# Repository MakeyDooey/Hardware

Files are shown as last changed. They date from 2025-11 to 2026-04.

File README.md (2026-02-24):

# Hardware
This includes all CAD files, PCB designs, schematics, datasheets, and designs. (includes enclosure and modularity components)

In it's current state I do not have a .gitignore for this repo. I will make one eventually and organize the repo more, but for now all KiCAD files are saved in the Schematic Folder as they are saved on my local computer

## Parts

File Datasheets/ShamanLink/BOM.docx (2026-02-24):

# ShamanLink

- ~~MicroSD Connector:~~ ~~https://www.digikey.com/en/products/detail/molex/0475710001/3262277~~ ~~$1.03~~
- ~~DualTVSProtection~~~~:~~~~https://www.digikey.com/en/products/detail/stmicroelectronics/USBLC6-2SC6/1040559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 ~~$0.36 x3~~
- ~~Tactile Button:~~ ~~https://www.digikey.com/en/products/detail/c-k/PTS645SL43SMTR92-LFS/3861373~~ ~~$0.36~~
- ~~LDO:~~ ~~https://www.digikey.com/en/products/detail/diodes-incorporated/AP7361C-33Y5-13/5638323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 ~~$0.50~~
- ~~Priority MUX:~~ ~~https://www.ti.com/product/TPS2117~~ ~~$1.15~~
- ~~Crystal:~~ ~~https://www.digikey.com/en/products/detail/ecs-inc/ECS-160-20-46X/2676589~~ ~~$0.37~~
- ~~MCU:~~ ~~https://www.digikey.com/en/products/detail/nxp-usa-inc/LPC55S69JBD64K/10649974~~ ~~$8.45~~
- ~~USB-C Receptacle:~~ ~~https://www.digikey.com/en/products/detail/gct/USB4105-GF-A/11198441~~ ~~$0.78~~
- ~~DualTVSProtection:~~~~https://www.digikey.com/en/products/detail/stmicroelectronics/USBLC6-2SC6/1040559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 ~~$0.36 x1~~
- ~~Polyfuse:~~ ~~1206L075/13.2WR~~ ~~https://www.digikey.com/en/products/detail/littelfuse-inc/1206L075-13-2WR/2520739~~ ~~$0.57~~
- ~~TVSProtection:~~ ~~https://www.arrow.com/en/products/sm712-02htg/littelfuse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 ~~$0.59~~
- ~~Connector:~~ ~~https://www.digikey.com/en/products/detail/jst-sales-america-inc/S6B-XH-A/1651034~~ ~~$0.27~~
- ~~Transceiver:~~ ~~https://www.ti.com/product/THVD1450/part-details/THVD1450D~~ ~~$2.78 SOIC option~~
- ~~SWDTagConnect:~~ ~~https://www.tag-connect.com/product/tc2030-idc-nl~~ ~~$33.95~~
- ~~MulticolorLED:~~ ~~https://www.digikey.com/en/products/detail/w%C3%BCrth-elektronik/150141M173100/4489960~~ ~~$0.50~~
- ~~Header Pins:~~ ~~https://www.digikey.com/en/products/detail/sullins-connector-solutions/PRPC036SAAN-RC/2775218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 ~~$0.85 for 3xmore than needed~~
- ~~SMD Ferrite Beads:~~ ~~MFBW1V1~~~~608-601-R~~ ~~https://www.digikey.com/en/products/detail/eaton-electronics-division/MFBW1V1608-221-R/13161138~~ ~~6x$0.10;~~
- ~~0805 ( >=0.125W rating; 1% tolerance; thick film) SMD Resistors~~~~:~~ ~~5x10k; 1x22;~~ ~~1x10k; 1x110k; 1x56k; 1x100k;~~ ~~2x5.1k; 1x10k; 1x20k; 1x1M~~ ~~2x10k;~~ ~~4x33;3x10k~~ ~~6x1k; 1x330; 2x10k; 2x0; 2x100k~~ ~~https://www.amazon.com/Chanzon-Resistor-Tolerance-Resistors-Certificated/dp/B08RYMY6XK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
- ~~1206 (>=0.25W rating) SMD Resistor:~~ ~~1x120~~ ~~https://www.amazon.com/dp/B08RYMYWG9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 (https://www.amazon.com/dp/B08RYMYWG9?s=industrial&sp_csd=d2lkZ2V0TmFtZT1zcF9kZXRhaWw)
- ~~0805 SMD Capacitors (>10V rating on all; dielectric matters):~~ ~~1x0.1uF; 1x10uF;~~ ~~2x10uF; 2x100nF; 2x4.7uF; 3x0.1uF;~~ ~~2x33pF;~~ ~~1x10nF; 1x 4.7nF; 10x0.1uF; 1x1uF; 2x10uF; 2x47pF; 1x100nF;~~ ~~2x0.1uF; 1x10uF;~~ ~~2x0.1uF~~~~;1x10uF~~ ~~1x0.1uF~~~~https://www.amazon.com/0805-Capacitor-Capacitors-Assortment-Folder/dp/B0D6RW7CZ8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
- ~~1206~~ ~~SMD Capacitors (>25V rating on all; dielectric matters)~~ ~~1x22uF;~~ ~~2x22uF;~~ ~~https://www.mouser.com/ProductDetail/Murata-Electronics/GRT31CC71E226ME13K?qs=xZFQr2mActe1lTnk7kyUaA%3D%3D~~
- ~~SMD Inductors:~~ ~~CDRH2D11NP-4R7NC~~ ~~https://www.digikey.com/en/products/detail/sumida-america-inc/CDRH2D11NP-4R7NC/2620830~~ ~~1x$0.75~~
- ~~0805 SMD LEDs:~~ ~~see the .csv file for links and datasheets 6->green,green,blue,yellow,yellow,red 6x$0.19 //make sure Vf < 3V on all LEDs and Vf > 1.5V for 2 LEDs in series with 33 ohm resistors~~
- ~~Programmer~~~~:~~ ~~https://www.digikey.com/en/products/detail/nxp-usa-inc/MCU-LINK/13536147~~
- ~~Solder materials~~~~: solder wire:~~ ~~https://www.amazon.com/Rosin-Solder-Electrical-Soldering-0-3mm/dp/B08M5XDKFG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 ~~, solder paste:~~ ~~https://www.amazon.com/Solder-Paste-clean-63Sn-syringe/dp/B07B3VHPJ8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 ~~, desoldering braid~~ ~~https://www.amazon.com/TOWOT-Desoldering-Disassemble-Electrical-Components/dp/B0943PDCC4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

# GeminiCHECKPowerBudgetShamanLink

### 1. The Power Supply Capability

- Source (USB-C): Standard USB 2.0 ports provide 500mA. USB 3.0 ports provide 900mA.
- Safety Fuse (Polyfuse 1206L075): This has a "Hold Current" of 750mA. This is your absolute input limit before the fuse starts acting like a resistor and cutting power.
- Voltage Regulator (LDO AP7361C):
  - Max Current: 1.0A (1000mA).
  - Constraint: While it can push 1A, it is limited by heat (see thermal check below).

Available Power Budget: Conservatively 500mA (limited by standard USB ports).

### 2. The Power Consumption (The Load)

We will calculate the "Worst Case" scenario (everything turned on and transmitting at once) for the 3.3V Rail.

Component | State | Estimated Current (mA) | Notes
LPC55S69 MCU | Active Run (96MHz) | ~18 mA | Using internal DC-DC (implied by 4.7µH inductor).
MicroSD Card | Write Mode (Peak) | ~100 mA | This is the biggest variable. Some cards spike higher, but 100mA is a safe standard budget.
THVD1450 (RS485) | Transmitting | ~60 mA | Assumes driving a standard 54Ω termination load.
6x LEDs | All On | ~8 mA | Your BOM lists 1kΩ resistors. $(3.3V - 2V) / 1000\Omega = 1.3mA$ per LED.
Multicolor LED | White (RGB On) | ~15 mA | Assumes ~5mA per channel.
TPS2117 Mux | On | ~0.1 mA | Negligible quiescent current.
Passive Leaks | TVS / Caps | ~0.1 mA | Negligible.
TOTAL (Peak) | | ~201.2 mA

Total Estimated Max Load: ~200 mA

### 3. Verification & Safety Margins

#### A. Current Capability [PASS]

- Demand: ~200mA
- Supply: 500mA (USB) / 1000mA (LDO) / 750mA (Fuse)
- Result: You are using roughly 40% of your available USB power. You have plenty of headroom for the MCU to boost its clock speed or for high-performance SD cards.

#### B. LDO Thermal Analysis [PASS]

This is critical. You are dropping 5V down to 3.3V. That extra voltage turns into heat.

- Voltage Drop: $5V - 3.3V = 1.7V$
- Current Load: $0.2A$ (200mA)
- Power Dissipated: $P = V \times I = 1.7 \times 0.2 = \mathbf{0.34 Watts}$

Your LDO (AP7361C) usually comes in SOT-89 or SOT-223 packages.

- Estimated Temp Rise: A standard SOT-89 package rises ~50°C per Watt.
- Calculation: $0.34W \times 50^\circ C/W \approx 17^\circ C$ rise.
- Result: If your room is 25°C, the LDO will run at roughly 42°C. This is warm to the touch but completely safe (well below the 125°C limit).

### 4. Special Component Notes

1. Inductor (CDRH2D11NP-4R7NC): This 4.7µH inductor matches the requirements for the LPC55S69 Internal DC-DC Converter. This is good design; it keeps the MCU current consumption low.
2. Resistors: The 1kΩ resistors you selected for the LEDs will make them quite dim (perfect for indicators that don't blind the user). If you want them brighter, you have plenty of power budget to swap them for 330Ω resistors later.
3. Polyfuse: The 750mA hold current is perfect. It protects the USB port without tripping during normal SD card spikes.

### Conclusion

Your power budget is solid. You have approximately 300mA of spare capacity on the 3.3V rail.

Component | State | Estimated Current (mA)
LPC55S69 MCU | Active Run (96MHz) | ~18 mA
MicroSD Card | Write Mode (Peak) | ~100 mA
THVD1450 (RS485) | Transmitting | ~60 mA
6x LEDs | All On | ~8 mA
Multicolor LED | White (RGB On) | ~15 mA
TPS2117 Mux | On | ~0.1 mA
Passive Leaks | TVS / Caps | ~0.1 mA
TOTAL (Peak) | Does not include powering a target board | ~201.2 mA

Power Supply: ~500mA max from USB 2.0

Power Usage: ~40%

This is the "sanity check" phase, and it is arguably the most critical step before you order. You are looking to verify three things: Current Capability (will traces melt?), Voltage Drop (will the voltage be too low by the time it reaches the chip?), and Thermals (will the LDO burn up?).

Here is your step-by-step guide to verifying your power design using KiCad’s built-in tools and some simple math.

### Step 1: Create Your "Power Budget"

Before you measure anything, you need to know what you are measuring against. You cannot verify a trace if you don't know how many Amps are flowing through it.

- List your max currents:
  - USB Input (5V): What is the max current your board will draw? (likely < 500mA for a standard USB 2.0 device).
  - LDO Output (3.3V): How much does the MCU + LEDs + Peripherals consume? (LPC55S69 is usually < 20mA, but LEDs can add up).
  - Target Power: If you are powering an external target, how much current does it need?

Example Budget:

- Input 5V: 500mA (Max)
- Main 3.3V Rail: 200mA (MCU + LED + headroom)

### Step 2: Verify Trace Widths (KiCad Calculator)

You selected trace widths earlier (0.2mm, 0.4mm, 0.8mm). Now, let's scientifically prove they are big enough.

1. Open KiCad Calculator: In the main KiCad project window, click the icon that looks like a calculator (or Tools -> Calculator Tools).
2. Go to the "Track Width" Tab.
3. Enter your parameters:
  - Current: Enter your max current (e.g., 0.5A for the USB line).
  - Temperature Rise: Standard is 10°C. (This means you are okay with the trace getting 10 degrees hotter than the room).
  - Trace Thickness: Standard 1oz copper is 35µm (0.035mm).
  - Trace Length: Enter a rough estimate (e.g., 20mm).
4. Result: Look at the "External Layer Track Width".
  - Example: For 0.5A, KiCad might say you need only 0.15mm.
  - Your Design: You used 0.8mm for power. Verdict: PASS (with huge safety margin).

Rule of Thumb: A 0.3mm trace can easily handle 1 Amp on external layers. Your 0.8mm power traces are likely bulletproof.

### Step 3: Check Your Vias (The Bottleneck)

Vias are the chokepoints of power. A single standard via cannot handle as much current as a wide trace.

1. In the Calculator: Switch to the "Via" tab (or look at the via section in Track Width).
2. Enter your Via size:
  - Hole Diameter: 0.3mm (standard small via) or 0.4mm (power via).
  - Plating Thickness: Standard is 18µm - 25µm.
3. Check the Current:
  - A single 0.3mm via can usually handle about 0.3A - 0.5A comfortably.
4. The Fix: If you need to pass 1A, use multiple vias.
  - Rule: Always use at least two vias for any power connection (input, output, ground). This adds redundancy and lowers resistance.
  - Action: Go to your layout and verify that your USB Connector Ground pins and LDO Ground tab have multiple vias stitching them to the Ground Plane.

### Step 4: The "LDO Thermal" Check (Critical!)

This is the most common failure point. Your LDO drops 5V to 3.3V. That energy is turned into heat.

1. Calculate Power Dissipation: $$P = (V_{in} - V_{out}) \times I_{load}$$
  - $V_{in} = 5V$
  - $V_{out} = 3.3V$
  - $I_{load} = 0.2A$ (Example)
  - $P = (5 - 3.3) \times 0.2 = 1.7 \times 0.2 = \mathbf{0.34 Watts}$
2. Check the Datasheet: Look for the "Thermal Resistance" ($R_{\theta JA}$) of your LDO package (e.g., SOT-23 or SOT-223).
  - SOT-23: A tiny package might heat up by $200^\circ C$ per Watt.
  - Calculation: $0.34W \times 200^\circ C/W = \mathbf{68^\circ C \text{ rise}}$.
  - Result: If your room is $25^\circ C$, the chip will be $93^\circ C$. That is HOT but safe (most silicon survives to $125^\circ C$).
3. The Fix: If the calculation shows over $100^\circ C$:
  - Use a bigger package (SOT-223 instead of SOT-23).
  - Add more copper area around the tab (the heatsink).
  - Add "Thermal Vias" in the central pad to dump heat into the ground plane.

### Step 5: Verify Passive Components

1. Resistors: Check any resistor carrying significant current (like LED current limiters).
  - $P = I^2 R$.
  - Example: 20mA through a 100-ohm resistor. $0.02^2 \times 100 = 0.04W$.
  - Rating: A standard 0402 resistor is rated for 0.063W (1/16W). This is close! An 0603 (0.1W) would be safer.
2. Inductors/Ferrite Beads: Check the "Rated Current" in the datasheet.
  - If your USB input has a Ferrite Bead, ensure it is rated for at least 1.5x your expected current (e.g., rated for 1A if you expect 500mA).

### Summary Checklist

1. [ ] Traces: Are power traces wider than the Calculator recommendation? (0.8mm is likely great).
2. [ ] Vias: Do main power connections have at least 2 vias?
3. [ ] LDO Heat: Did you calculate the temperature rise? Is it under $100^\circ C$?
4. [ ] Passives: Are your resistors big enough (0603 vs 0402) for the power they dissipate?

Do you want to run the calculation for your specific LDO right now? If you give me the Part Number and your Estimated Current, I can tell you if it will overheat.

# MainTotemDemo

# MotorTotemDemo

# ModuleTotemDemo

# Scratchpad

## 1. Electrical & Physical Cleanup

- Run the Design Rules Checker (DRC): This is the most important step. Click the Bug icon in the top toolbar. It will catch any accidental shorts, traces that are too close together, or vias that didn't actually connect to the ground plane.
- Refill All Zones: Press the B key. This recalculates all copper pours. If you moved a via or trace, the copper plane might have a "hole" in it that needs to be filled.
- Check for "Islands": Look for any floating bits of copper that aren't connected to anything. KiCad’s DRC will usually flag these as "Unconnected items."
- Inspect Thermal Vias: Verify that your ground vias for U3 still show the GND net and are correctly merged into the bottom ground plane.

## 2. Silkscreen & Aesthetics

- Fix Overlapping Text: As we discussed, make sure C17, U3, and other labels aren't sitting on top of via holes or pads.
- Check Component Polarity: Ensure that "Pin 1" markers (dots or notches) are visible on the silkscreen so you don't solder the chips on backward.
- Add Board Information: It is always a good idea to add your name, the project title, the date, and a version number (e.g., "v1.0") to the F.Silk or B.Silk layer.
- Add Logos: If you want a "Certified Open Source" logo or a personal icon, add it now!

## 3. Hand-Soldering Optimizations

- Check Mask Openings: Use the 3D Viewer (Alt + 3) to confirm that the purple/pink areas (solder mask openings) are present on all pads you need to solder.
- Verify Clearance: Ensure there is enough physical room between components for your soldering iron tip to reach the pads without melting the plastic casing of a neighboring part.

## 4. Output Generation (The "Manufacturing" Files)

Once the DRC shows 0 Errors and 0 Warnings, it’s time to generate the files for the factory:

1. Generate Gerbers: Go to File > Fabrication Outputs > Gerbers (.gbr). Select all copper layers, Silkscreen, Mask, and the Edge.Cuts (board outline) layer.
2. Generate Drill Files: In the same menu, click Generate Drill Files. Use the default settings (Excellon format).
3. Create a ZIP: Put all the generated .gbr and .drl files into a single ZIP folder. This is what you will upload to the manufacturer's website.

## 5. Final Visual Audit

- The "Paper Test": Some designers print the layout at 1:1 scale on a piece of paper and physically place their components on the paper to ensure the footprints are the correct size.
- Inspect the Bottom Layer: Flip the 3D model over. Ensure your ground plane is solid and your thermal vias are clearly visible for that "solder injection" trick.

6. Check that traces width all match their power amounts

7. Check your paper to make sure you have done everything

8. Read through all datasheets to make sure you followed all instructions and that the components you used all correctly match your power requirements.

9. Document out all of the PCB design process with specific steps so it’s easy to follow again and include everything you learned such as the powerpoint presentation tips on width for traces etc etc. all the Gemini stuff. Go through every prompt

10. Upload everything to GitHub and organize all of the ShamanLink documentation into the GitHub as well….. Email erosen

11. Final verifications of everything and order the PCB

12. Make sure all vias that need to be tented are tented

Root Power RS485Transceiver HeaderLEDs MainTotemHeader MicroSD Clocks

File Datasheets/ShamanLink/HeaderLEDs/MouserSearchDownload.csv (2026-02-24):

Mouser Part Number | Mfr Part Number | Mfr. | Datasheet | Availability | Pricing | RoHS | Lifecycle | Product Detail | Product | Mounting Style | Package / Case | Wavelength/Color Temperature | Illumination Color | If - Forward Current | Vf - Forward Voltage | Power Rating | Lens Color | Lens Dimensions | Lens Shape | Lens Transparency | Series | Packaging
710-150080GS75000 | 150080GS75000 | Wurth Elektronik | https://www.we-online.com/components/products/datasheet/150080GS75000.pdf | 84,051 In Stock | ="$0.19" | RoHS Compliant |  | https://www.mouser.com/ProductDetail/Wurth-Elektronik/150080GS75000 | Green LEDs | SMD/SMT | 0805 (2012 metric) | 520 nm | Green | 20 mA | 3.2 V | 105 mW | Colorless | 1.4 mm x 1.25 mm | Rectangular | Water Clear | WL-SMCW | Reel, Cut Tape, MouseReel
710-150080VS75000 | 150080VS75000 | Wurth Elektronik | https://www.we-online.com/components/products/datasheet/150080VS75000.pdf | 23,543 In Stock | ="$0.19" | RoHS Compliant |  | https://www.mouser.com/ProductDetail/Wurth-Elektronik/150080VS75000 | Green LEDs | SMD/SMT | 0805 (2012 metric) | 570 nm | Green | 20 mA | 2 V | 72 mW | Colorless | 1.4 mm x 1.25 mm | Rectangular | Water Clear | WL-SMCW | Reel, Cut Tape, MouseReel
710-150080YS75000 | 150080YS75000 | Wurth Elektronik | https://www.we-online.com/components/products/datasheet/150080YS75000.pdf | 29,472 In Stock | ="$0.19" | RoHS Compliant |  | https://www.mouser.com/ProductDetail/Wurth-Elektronik/150080YS75000 | Yellow LEDs | SMD/SMT | 0805 (2012 metric) | 590 nm | Yellow | 20 mA | 2 V | 72 mW | Colorless | 1.4 mm x 1.25 mm | Rectangular | Water Clear | WL-SMCW | Reel, Cut Tape, MouseReel
710-150080BS75000 | 150080BS75000 | Wurth Elektronik | https://www.we-online.com/components/products/datasheet/150080BS75000.pdf | 21,273 In Stock | ="$0.19" | RoHS Compliant |  | https://www.mouser.com/ProductDetail/Wurth-Elektronik/150080BS75000 | Blue LEDs | SMD/SMT | 0805 (2012 metric) | 470 nm | Blue | 20 mA | 3.2 V | 105 mW | Colorless | 1.4 mm x 1.25 mm | Rectangular | Water Clear | WL-SMCW | Reel, Cut Tape, MouseReel
710-150080RS75000 | 150080RS75000 | Wurth Elektronik | https://www.we-online.com/components/products/datasheet/150080RS75000.pdf | 71,734 In Stock | ="$0.19" | RoHS Compliant |  | https://www.mouser.com/ProductDetail/Wurth-Elektronik/150080RS75000 | Red LEDs | SMD/SMT | 0805 (2012 metric) | 625 nm | Red | 20 mA | 2 V | 72 mW | Colorless | 1.4 mm x 1.25 mm | Rectangular | Water Clear | WL-SMCW | Reel, Cut Tape, MouseReel
710-150080AS75000 | 150080AS75000 | Wurth Elektronik | https://www.we-online.com/components/products/datasheet/150080AS75000.pdf |  | ="$0.25" | RoHS Compliant |  | https://www.mouser.com/ProductDetail/Wurth-Elektronik/150080AS75000 | Amber LEDs | SMD/SMT | 0805 (2012 metric) | 605 nm | Amber | 20 mA | 2 V | 72 mW | Colorless | 1.4 mm x 1.25 mm | Rectangular | Water Clear | WL-SMCW | Reel, Cut Tape, MouseReel
710-150080SS75000 | 150080SS75000 | Wurth Elektronik | https://www.we-online.com/components/products/datasheet/150080SS75000.pdf |  | ="$0.19" | RoHS Compliant |  | https://www.mouser.com/ProductDetail/Wurth-Elektronik/150080SS75000 | Red LEDs | SMD/SMT | 0805 (2012 metric) | 630 nm | Red | 20 mA | 1.9 V | 72 mW | Colorless | 1.4 mm x 1.25 mm | Rectangular | Water Clear | WL-SMCW | Reel, Cut Tape, MouseReel

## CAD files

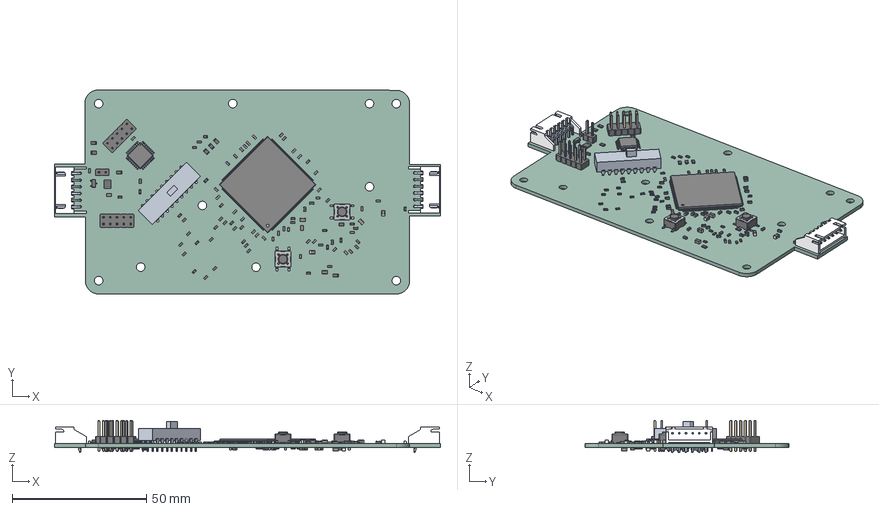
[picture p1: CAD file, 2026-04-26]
CAD/MainTotem_Rev1.step
143.9 x 76.1 x 11.9 mm
R_0603_1608Metric x 57
C_0603_1608Metric x 59
R_0805_2012Metric x 8
SOT-23
SW_SPST_PTS645Sx43SMTR92 x 2
C_0805_2012Metric x 9
LQFP-176
PinHeader_1x02_P2.54mm_Vertical
SxB-XH-A_6 x 2
pin^SxB-XH-A ass_bent x 4
pin^SxB-XH-A ass x 8
6PDTSwitch
R_1210_3225Metric
PinHeader_2x05_P2.54mm_Vertical x 2
STM32G0
MainTotem_Rev1_PCB

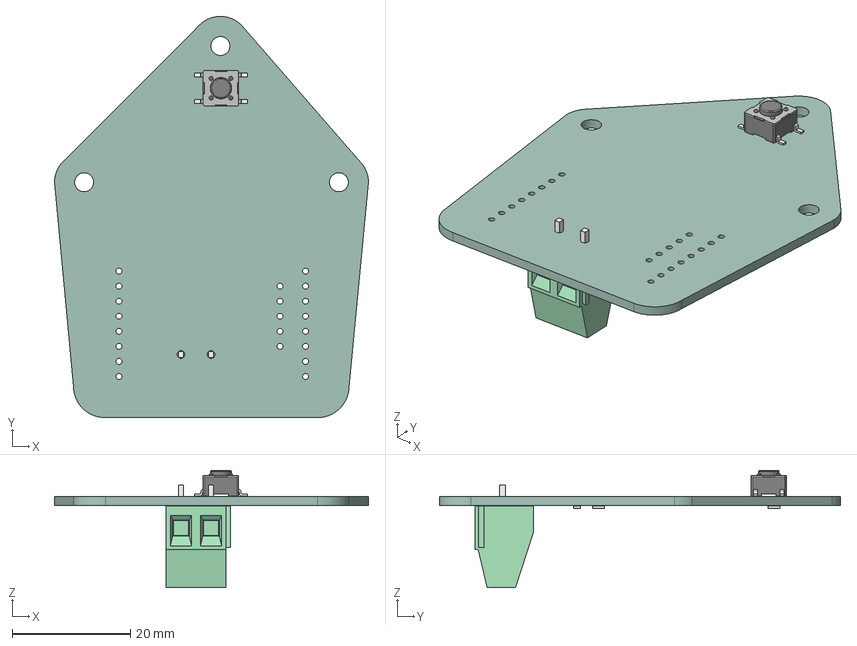
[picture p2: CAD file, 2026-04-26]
CAD/ComputerVisionModule_Rev1.step
53.0 x 67.7 x 19.8 mm
SW_SPST_PTS645Sx43SMTR92
TerminalBlock_Phoenix_MKDS-1,5-2-5.08_1x02_P5.08mm_Horizontal
R_0805_2012Metric x 3
ComputerVisionModule_Rev1_PCB

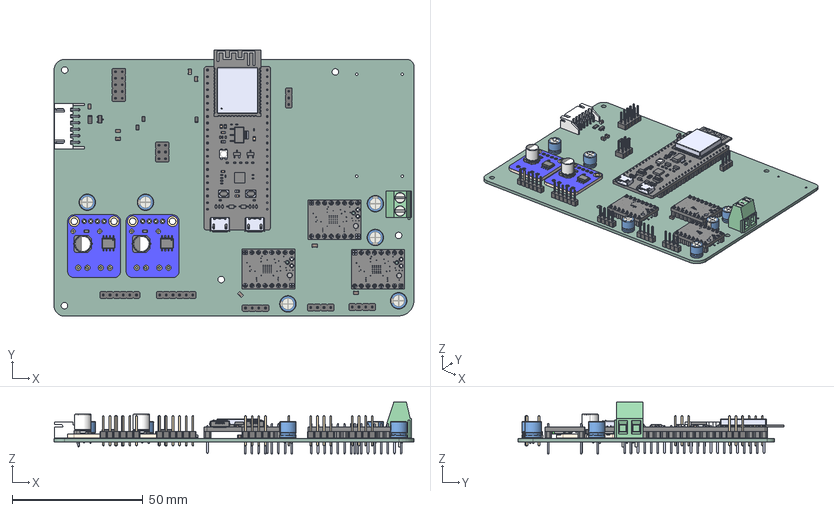
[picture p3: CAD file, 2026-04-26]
CAD/MotorTotem_Rev1.step
137.8 x 102.0 x 19.9 mm
TMC2209_SILENTSTEPSTICK x 3
R_0805_2012Metric x 3
CP_Radial_D6.3mm_P2.50mm x 6
PinHeader_2x05_P2.54mm_Vertical
C_0805_2012Metric x 8
Panasonic_D_22uF_63V_Panasonic_D_22uF_63V x 2
DRV8871_DRV8871 x 2
ESP32-S3-DEVKITC-1-N8R8
TerminalBlock_Phoenix_MKDS-1,5-2-5.08_1x02_P5.08mm_Horizontal
PinHeader_1x04_P2.54mm_Vertical x 3
PinHeader_2x03_P2.54mm_Vertical
SOT-23
PinHeader_1x06_P2.54mm_Vertical x 2
R_1206_3216Metric
PinHeader_1x03_P2.54mm_Vertical
SxB-XH-A_6
pin^SxB-XH-A ass_bent x 2
pin^SxB-XH-A ass x 4
MotorTotem_Rev1_PCB

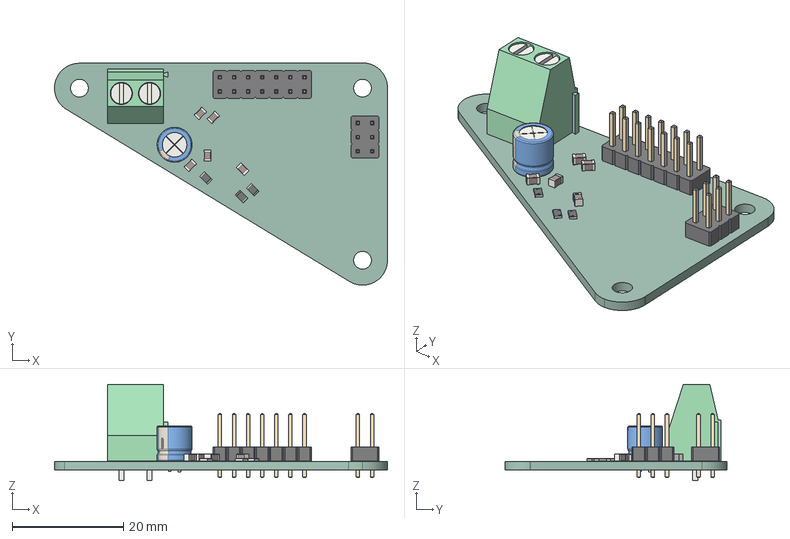
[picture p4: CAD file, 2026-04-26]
CAD/TouchScreenModule_Rev1.step
60.0 x 40.1 x 17.3 mm
R_0805_2012Metric x 3
PinHeader_2x07_P2.54mm_Vertical
C_0805_2012Metric x 5
PinHeader_2x03_P2.54mm_Vertical
TerminalBlock_Phoenix_MKDS-1,5-2-5.08_1x02_P5.08mm_Horizontal
CP_Radial_D6.3mm_P2.50mm
TouchScreenModule_Rev1_PCB

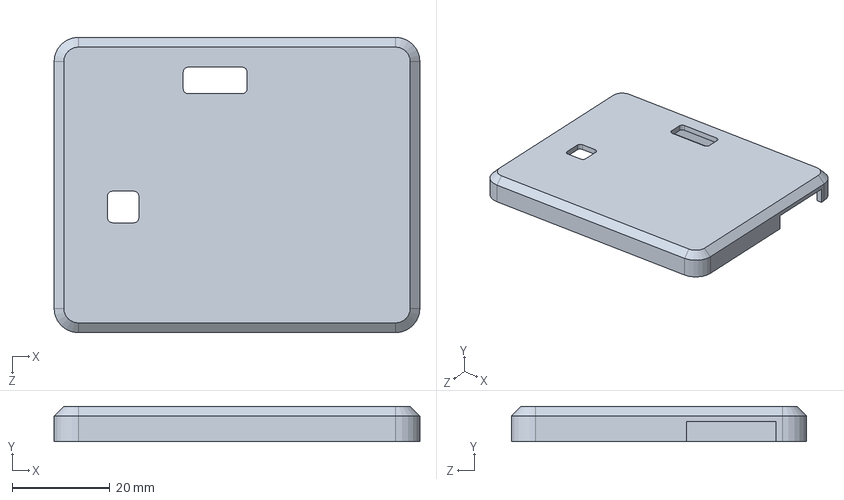
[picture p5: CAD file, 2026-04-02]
CAD/Enclosure Bottom.SLDPRT
74.8 x 7.23 x 60.4 mm

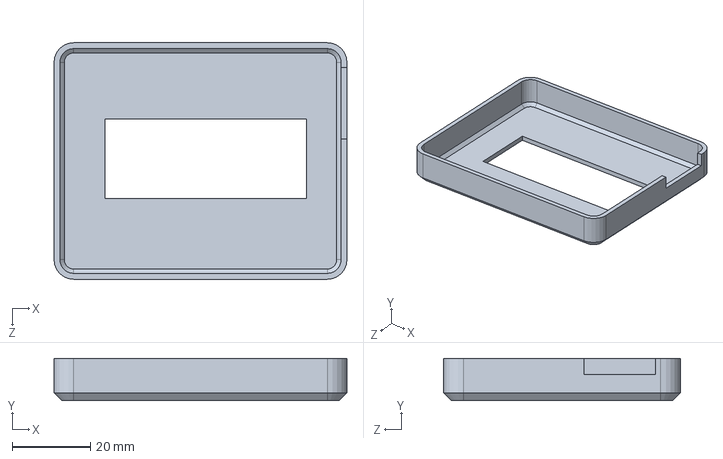
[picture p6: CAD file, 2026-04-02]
CAD/Enclosure Top.SLDPRT
74.8 x 10.8 x 60.4 mm

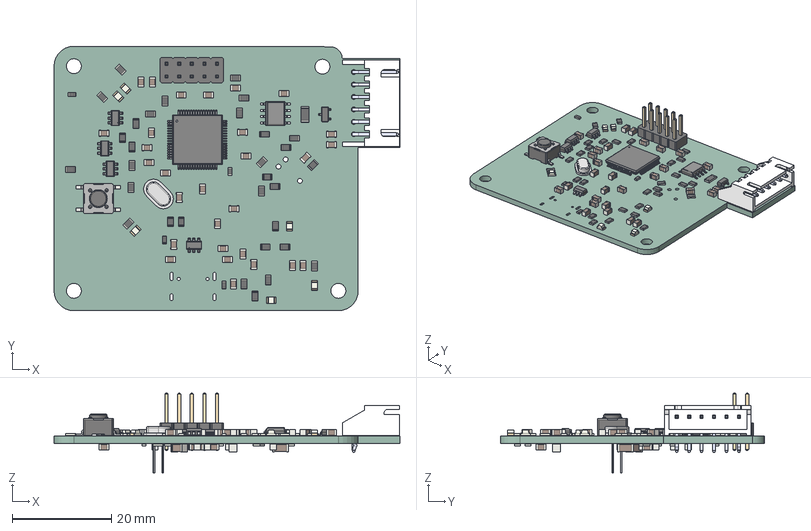
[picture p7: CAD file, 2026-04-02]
CAD/ShamanLink_Rev1.step
69.6 x 53.2 x 16.0 mm
R_0603_1608Metric x 6
C_0805_2012Metric x 39
BODY-SO
LEAD-D0008A x 8
PinHeader_2x05_P2.54mm_Vertical
R_0805_2012Metric x 38
SOT23-6L_STM x 4
LED_0805_2012Metric x 6
ECS-160-20-46X
SW_SPST_PTS645Sx43SMTR92
R_1206_3216Metric
HTQFP64_SOT855-5_NXP
SOT-23
SxB-XH-A_6
pin^SxB-XH-A ass_bent x 2
pin^SxB-XH-A ass x 4
C_1206_3216Metric x 3
ShamanLink_Rev1_PCB

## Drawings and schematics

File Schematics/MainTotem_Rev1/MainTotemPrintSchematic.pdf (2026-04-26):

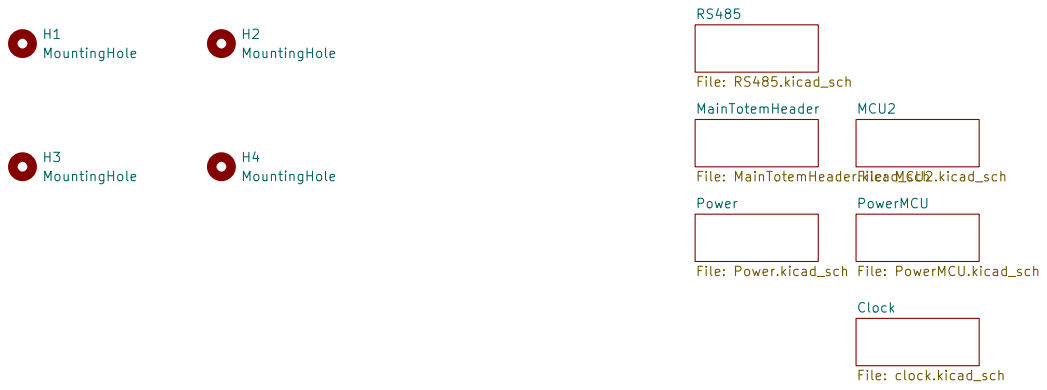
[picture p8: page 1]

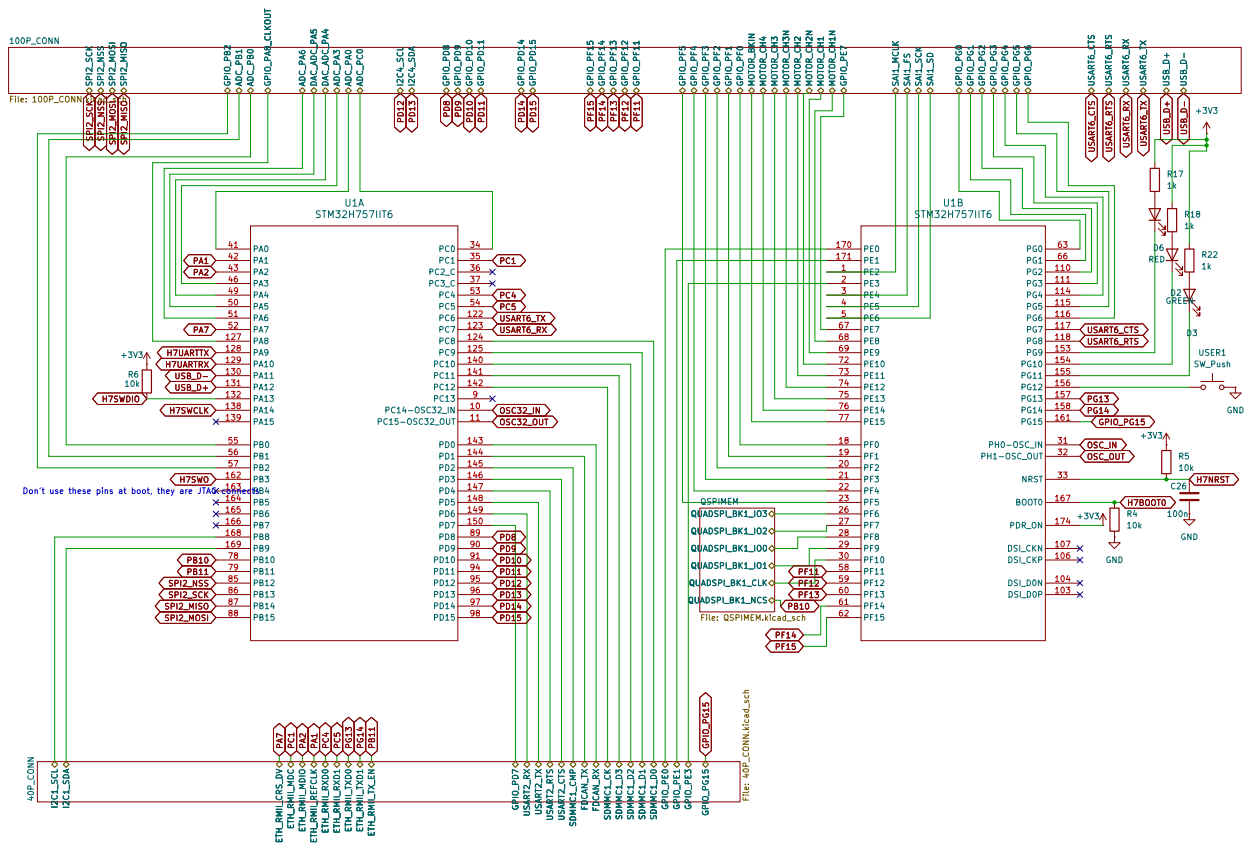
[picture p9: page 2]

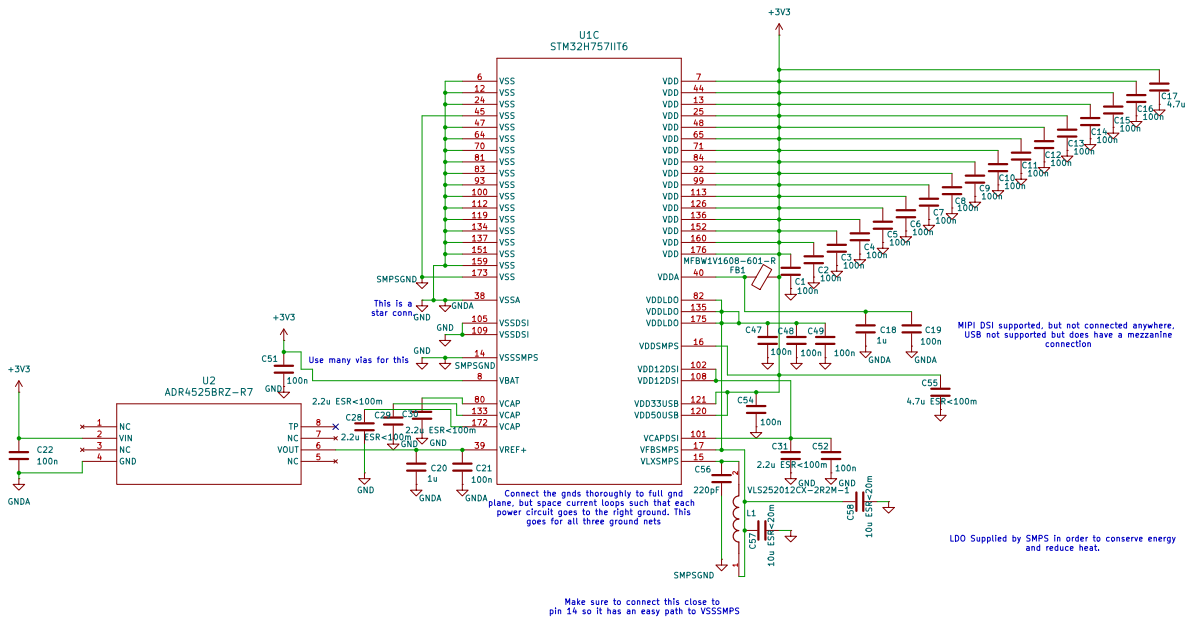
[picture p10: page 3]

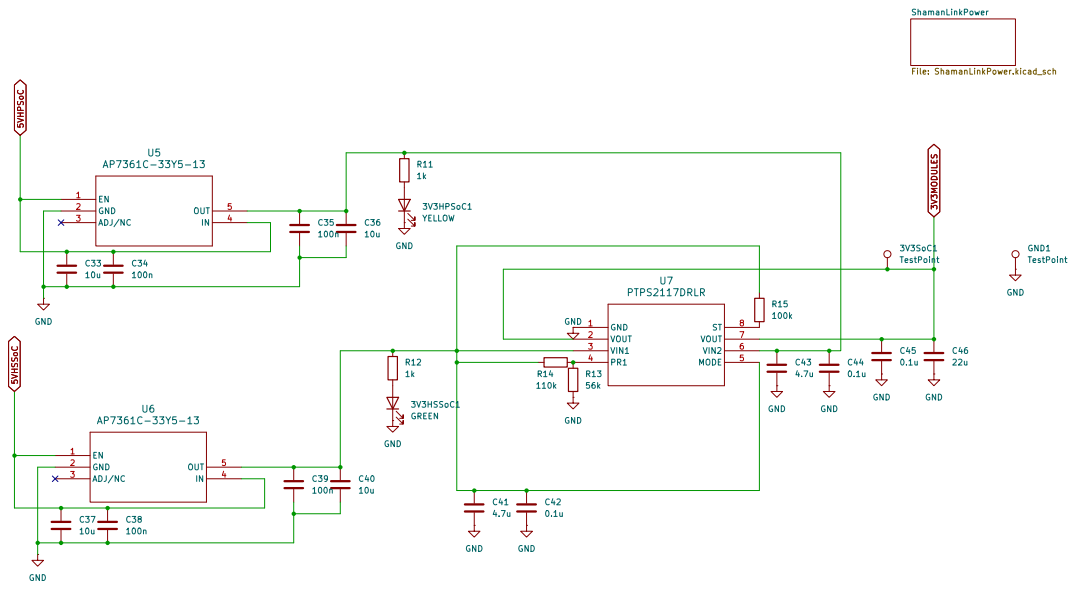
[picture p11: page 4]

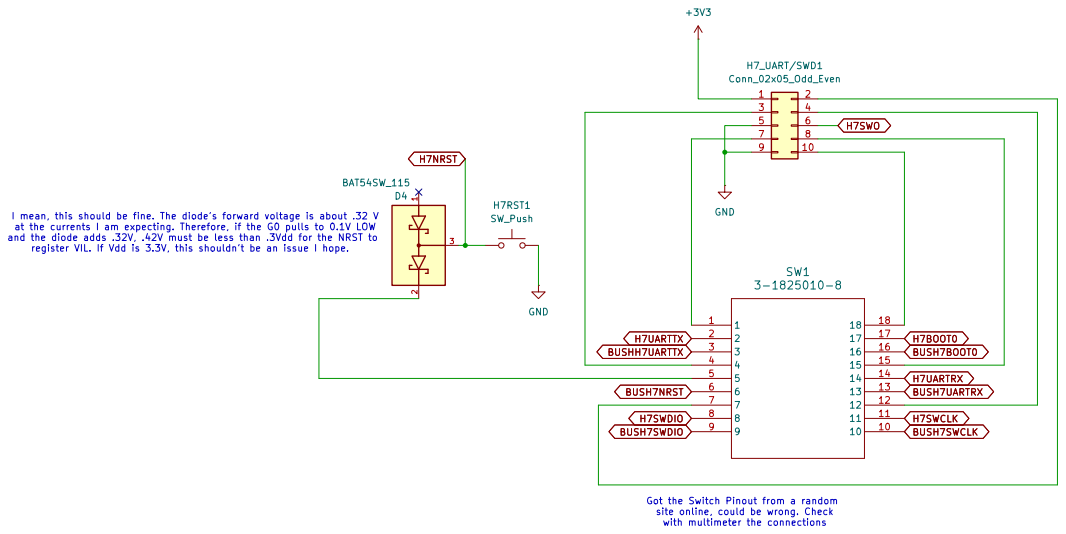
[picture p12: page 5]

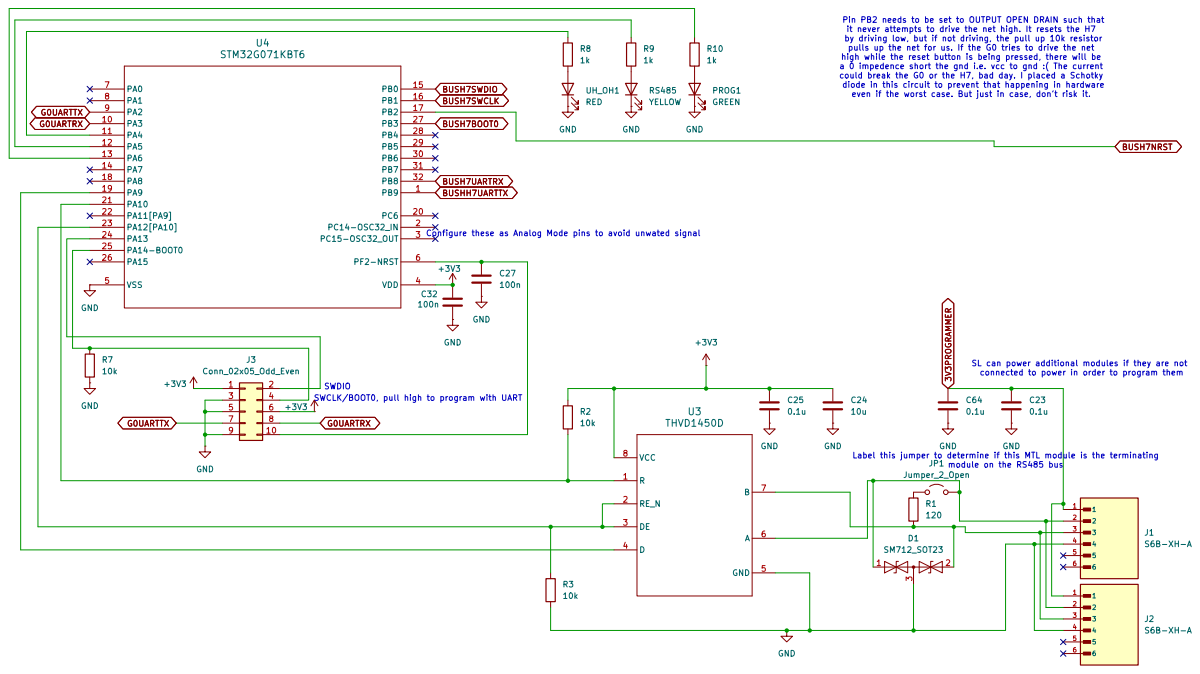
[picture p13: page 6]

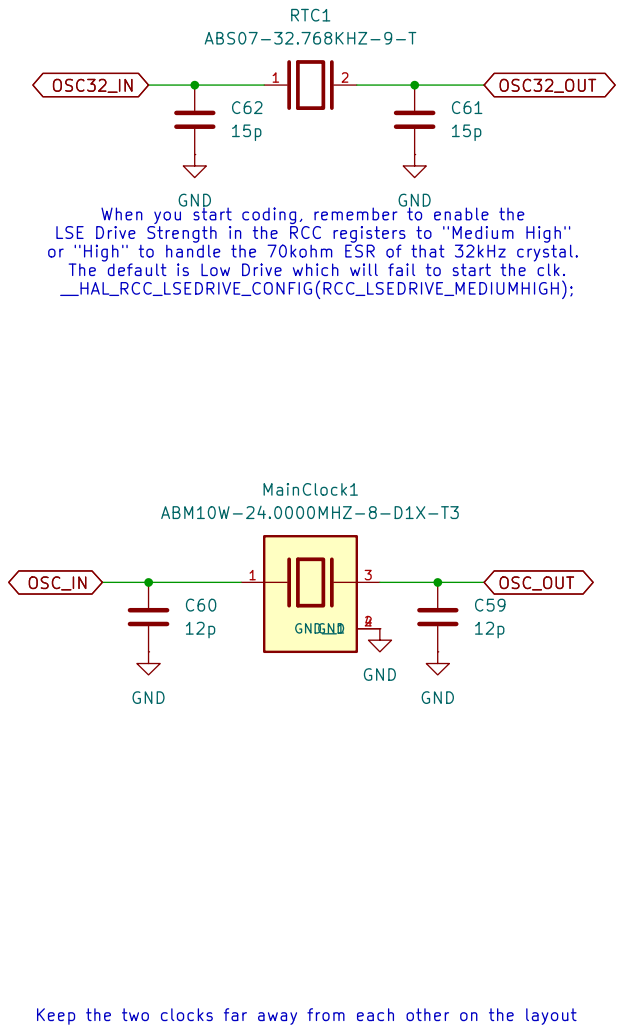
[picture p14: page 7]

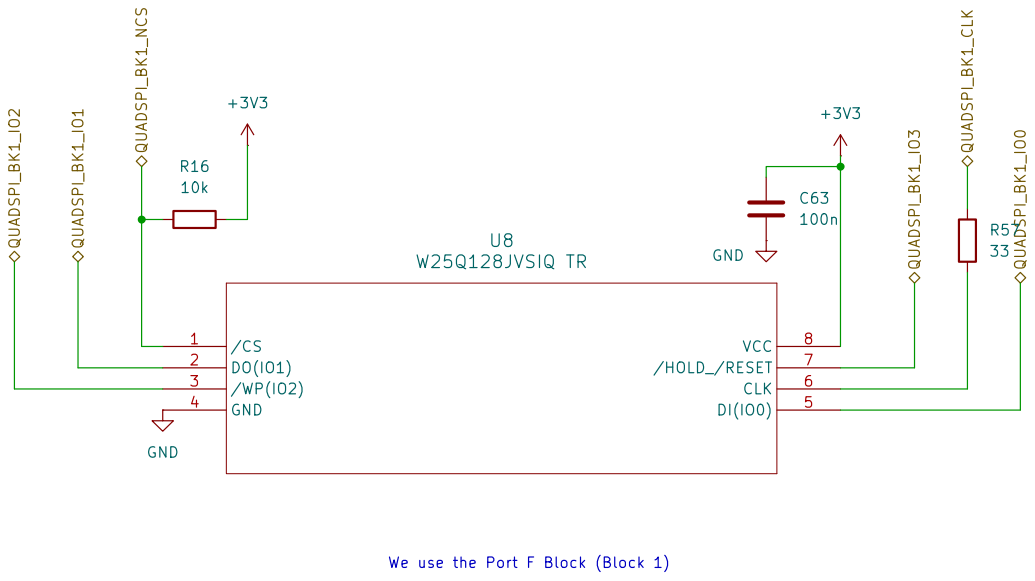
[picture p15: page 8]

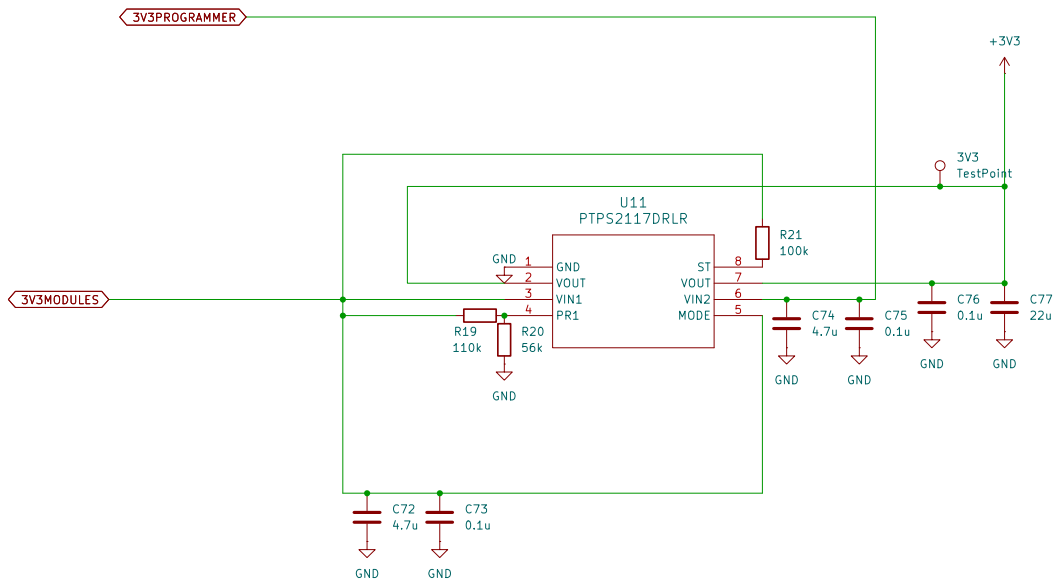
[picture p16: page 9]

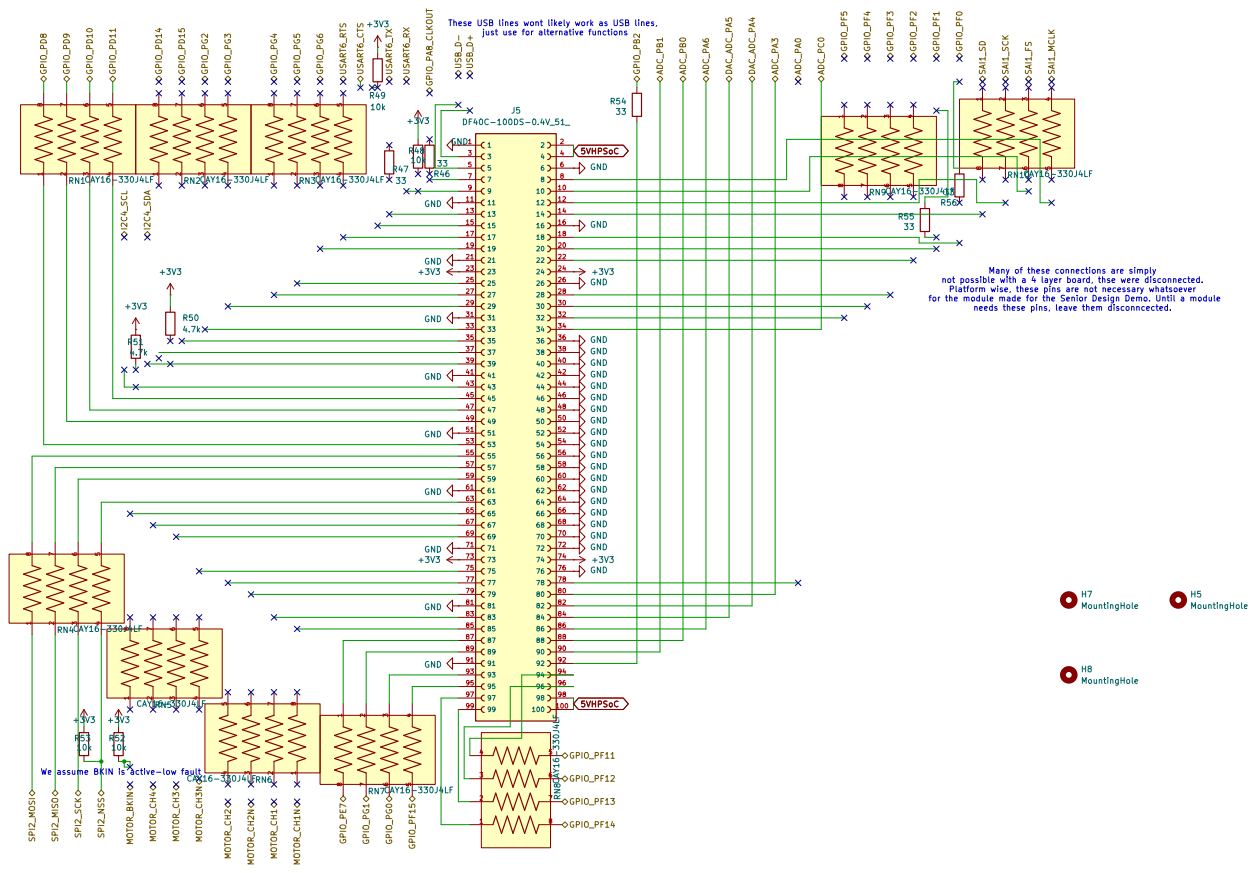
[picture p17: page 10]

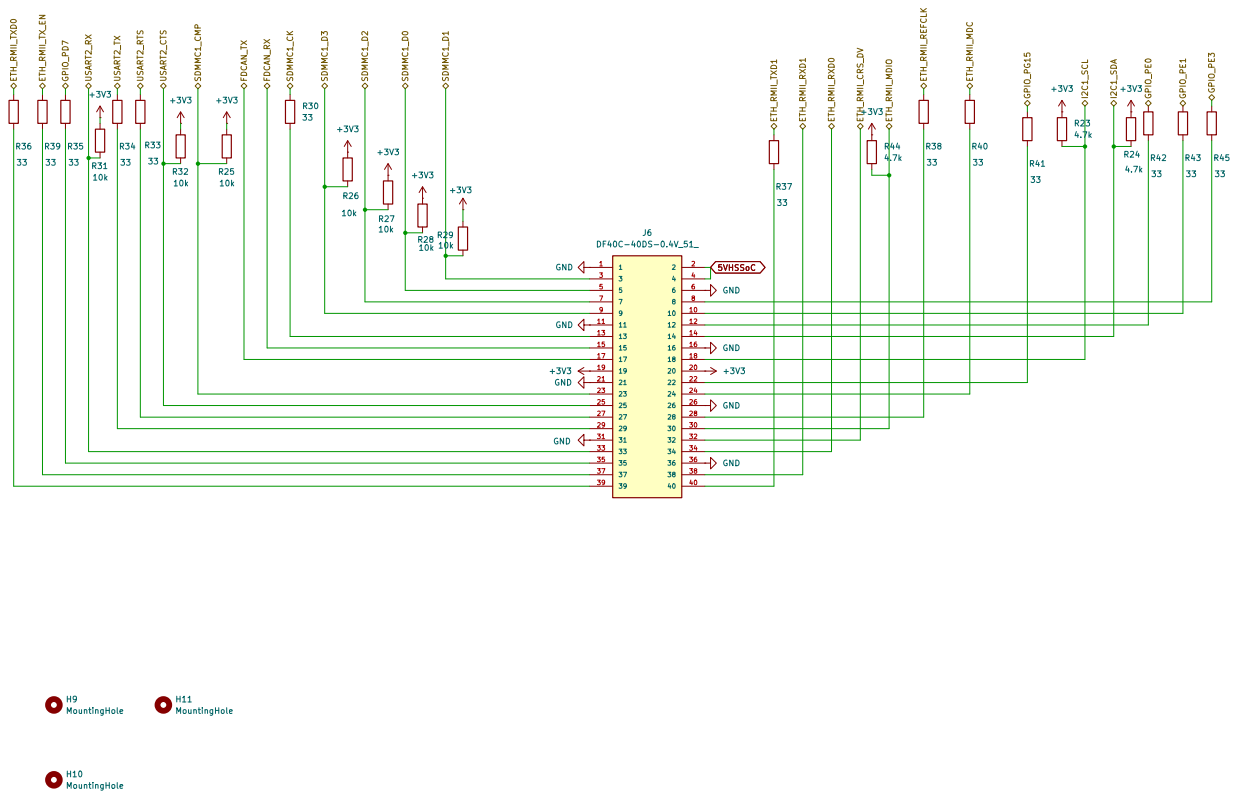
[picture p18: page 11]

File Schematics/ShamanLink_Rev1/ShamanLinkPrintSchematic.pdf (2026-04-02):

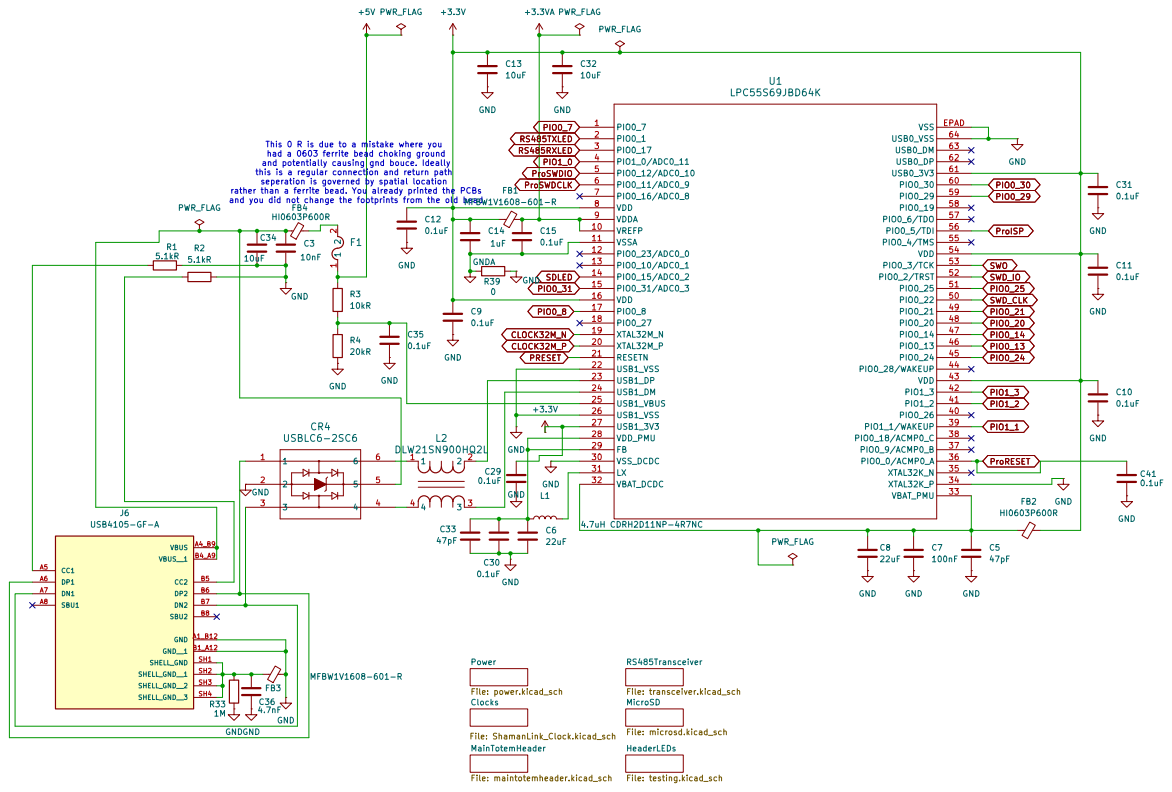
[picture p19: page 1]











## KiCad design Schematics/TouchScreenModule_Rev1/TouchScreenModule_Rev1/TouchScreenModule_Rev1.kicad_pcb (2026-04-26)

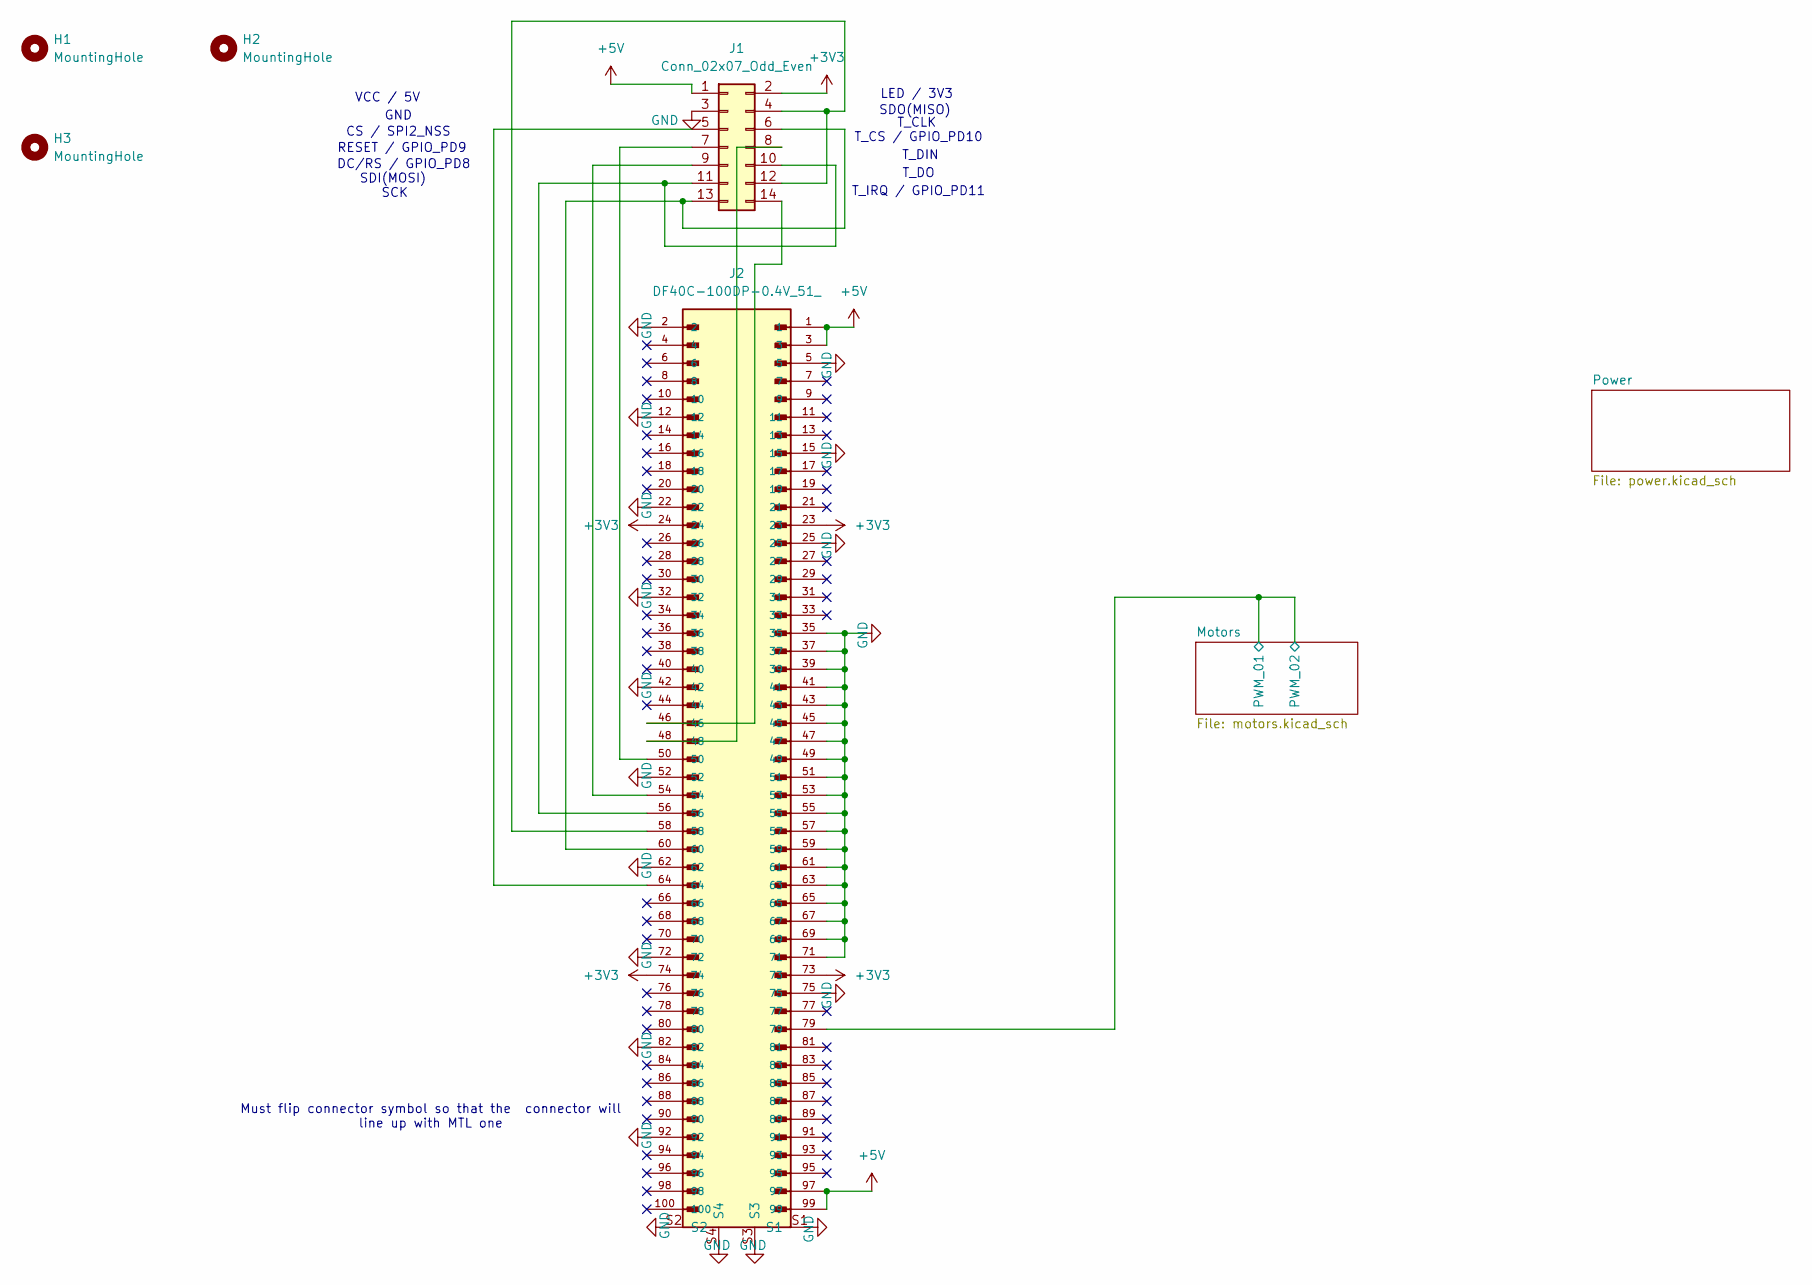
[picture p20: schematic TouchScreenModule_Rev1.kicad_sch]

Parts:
H1, H2, H3: MountingHole; MountingHole_3.2mm_M3_Pad_TopOnly
J1: Conn_02x07_Odd_Even; PinHeader_2x07_P2.54mm_Vertical
J2: DF40C-100DP-0.4V_51_; HIROSE_DF40C-100DP-0.4V_51_; PARTREV 8

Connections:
+3V3: J1.2, J2.23, J2.24, J2.73, J2.74
+5V: J1.1, J2.1, J2.3, J2.97, J2.99; also elsewhere on the board
/Motors/PWM_01: J2.79; also elsewhere on the board
GND: J1.3, J2.2, J2.5, J2.12, J2.15, J2.22, J2.25, J2.32, J2.35, J2.37, J2.39, J2.41, J2.42, J2.43, J2.45, J2.47, J2.49, J2.51, J2.52, J2.53, J2.55, J2.57, J2.59, J2.61, J2.62, J2.63, J2.65, J2.67, J2.69, J2.71, J2.72, J2.75, J2.82, J2.92, J2.S1, J2.S2, J2.S3, J2.S4; also elsewhere on the board
unnamed: J1.5, J2.64
unnamed: J1.7, J2.50
unnamed: J1.8, J2.48
unnamed: J1.9, J2.54
unnamed: J1.10, J1.11, J2.56
unnamed: J1.4, J1.12, J2.58
unnamed: J1.6, J1.13, J2.60
unnamed: J1.14, J2.46

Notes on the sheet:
T_CLK
CS / SPI2_NSS
GND
SCK
T_IRQ / GPIO_PD11
T_CS / GPIO_PD10
SDI(MOSI)
RESET / GPIO_PD9
T_DIN
T_DO
VCC / 5V
DC/RS / GPIO_PD8
SDO(MISO)
Must flip connector symbol so that the connector will line up with MTL one
LED / 3V3

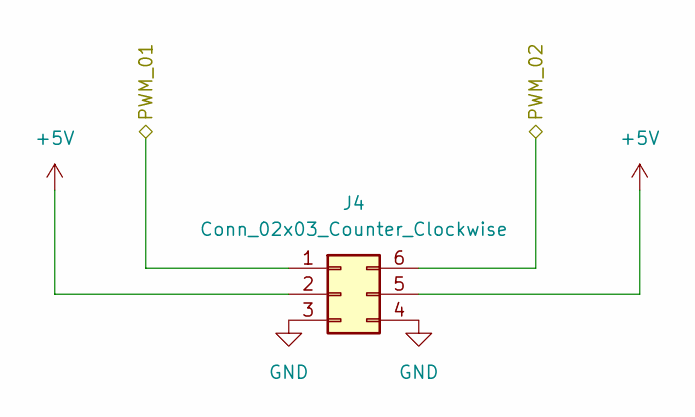
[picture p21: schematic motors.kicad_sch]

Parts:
J4: Conn_02x03_Counter_Clockwise; PinHeader_2x03_P2.54mm_Vertical

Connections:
+5V: J4.2, J4.5; also elsewhere on the board
/Motors/PWM_01: J4.1, J4.6; also elsewhere on the board
GND: J4.3, J4.4; also elsewhere on the board

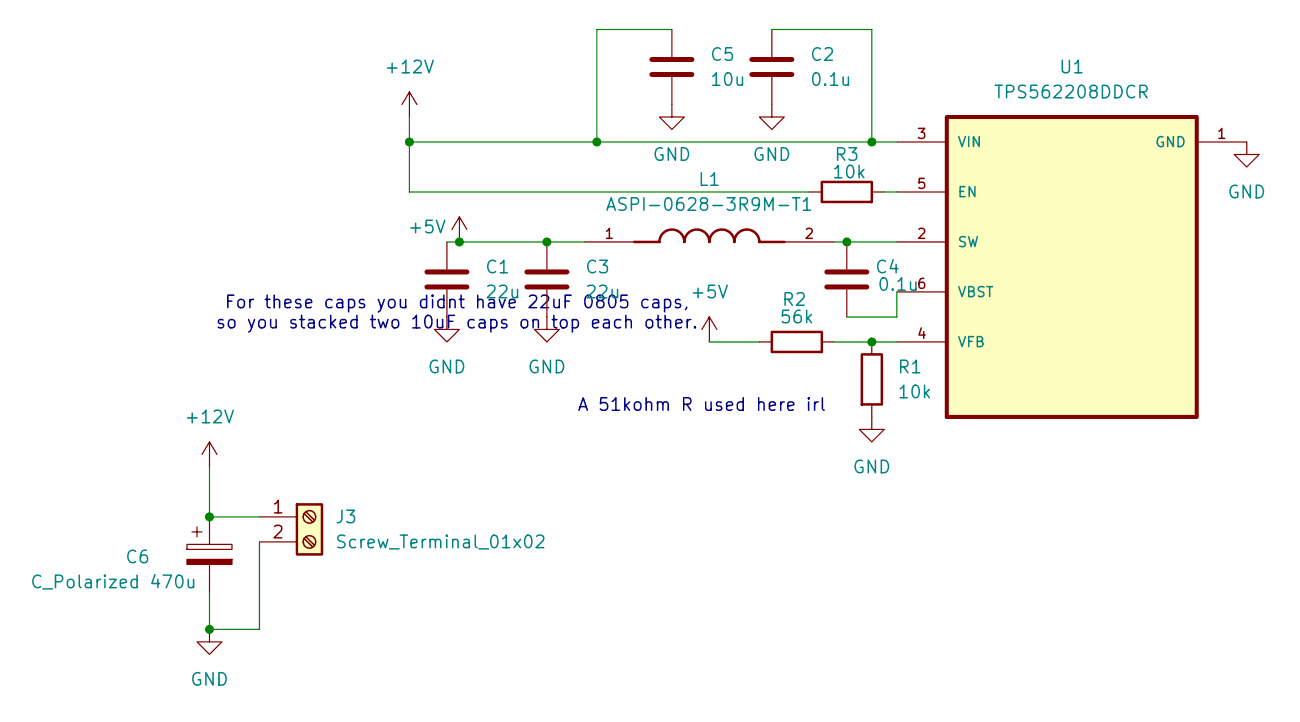
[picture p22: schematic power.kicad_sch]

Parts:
C1, C3: 22u; C_0805_2012Metric_Pad1.18x1.45mm_HandSolder
C2, C4: 0.1u; C_0805_2012Metric_Pad1.18x1.45mm_HandSolder
C5: 10u; C_0805_2012Metric_Pad1.18x1.45mm_HandSolder
C6: C_Polarized 470u; CP_Radial_D6.3mm_P2.50mm
J3: Screw_Terminal_01x02; TerminalBlock_Phoenix_MKDS-1,5-2-5.08_1x02_P5.08mm_Horizont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
L1: ASPI-0628-3R9M-T1; IND_ASPI-0628-3R9M-T1; PARTREV 6/30/2022
R1, R3: 10k; R_0805_2012Metric_Pad1.20x1.40mm_HandSolder
R2: 56k; R_0805_2012Metric_Pad1.20x1.40mm_HandSolder
U1: TPS562208DDCR

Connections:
+5V: C1.1, C3.1, L1.1, R2.1; also elsewhere on the board
+12V: C2.1, C5.1, C6.1, J3.1, R3.1, U1.3 (VIN)
GND: C1.2, C2.2, C3.2, C5.2, C6.2, J3.2, R1.2, U1.1 (GND); also elsewhere on the board
unnamed: R3.2, U1.5 (EN)
unnamed: C4.2, L1.2, U1.2 (SW)
unnamed: C4.1, U1.6 (VBST)
unnamed: R1.1, R2.2, U1.4 (VFB)

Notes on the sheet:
For these caps you didnt have 22uF 0805 caps, so you stacked two 10uF caps on top each other.
A 51kohm R used here irl

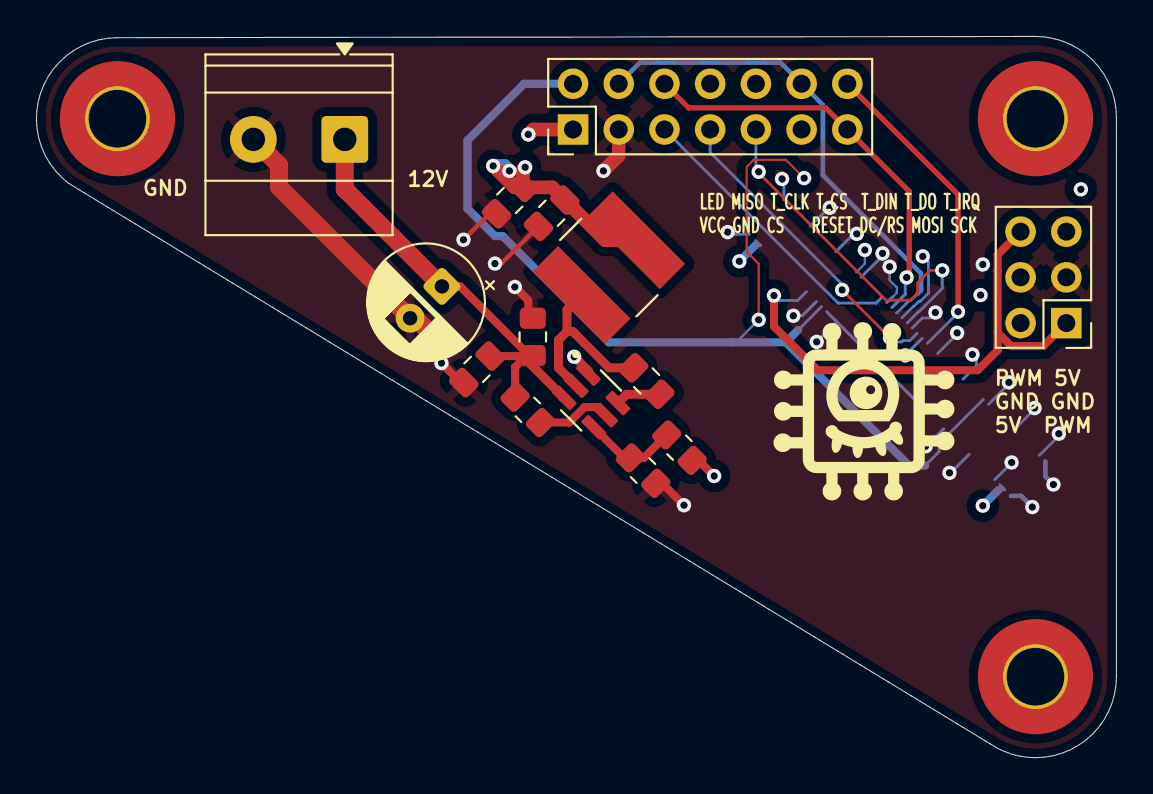
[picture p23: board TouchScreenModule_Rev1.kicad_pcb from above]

Board: 4 copper layers, 60.0 x 40.1 mm, 18 parts (1 on the bottom side), 17 nets.

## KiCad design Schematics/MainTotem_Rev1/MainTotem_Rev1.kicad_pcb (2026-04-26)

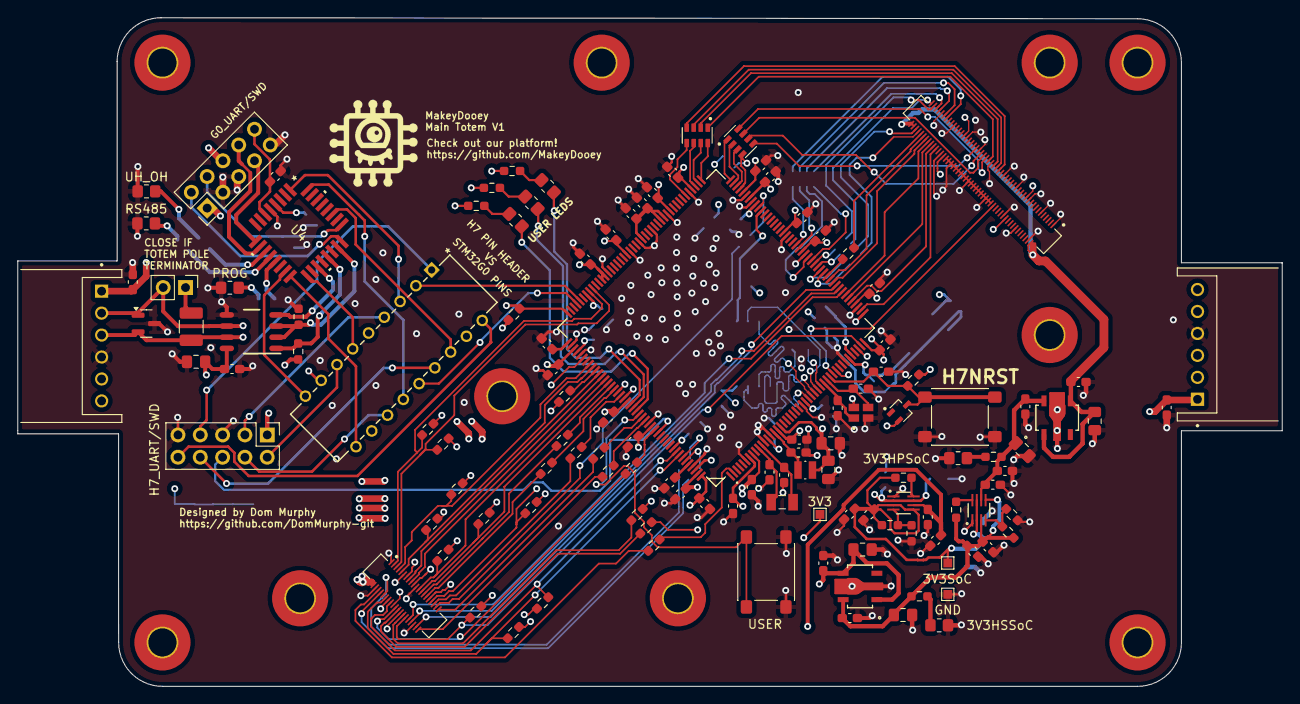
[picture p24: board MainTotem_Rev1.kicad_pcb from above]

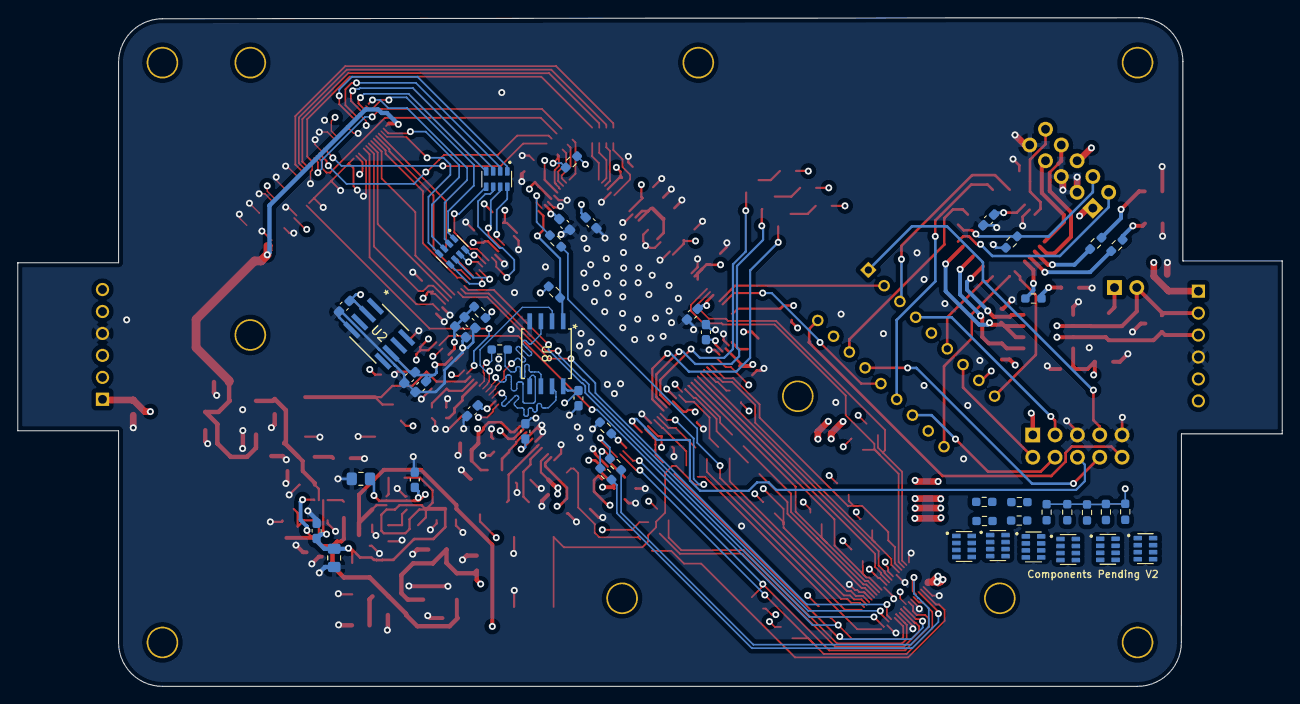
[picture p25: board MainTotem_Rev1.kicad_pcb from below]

Board: 4 copper layers, 143.9 x 76.1 mm, 181 parts (48 on the bottom side), 159 nets.

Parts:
3V3, 3V3SoC: TestPoint; TestPoint_Pad_1.0x1.0mm
3V3HPSoC: YELLOW; R_0805_2012Metric_Pad1.20x1.40mm_HandSolder
3V3HSSoC: GREEN; R_0805_2012Metric_Pad1.20x1.40mm_HandSolder
C1, C2, C3, C4, C5, C6, C7, C8, C9, C10, C11, C12, C13, C14, C15, C16, C19, C21, C22, C26, C27, C32, C34, C35, C38, C39, C47, C48, C49, C51, C52, C54, C63: 100n; C_0603_1608Metric_Pad1.08x0.95mm_HandSolder
C17, C41, C43, C72, C74: 4.7u; C_0603_1608Metric_Pad1.08x0.95mm_HandSolder
C18, C20: 1u; C_0603_1608Metric_Pad1.08x0.95mm_HandSolder
C23, C25, C42, C44, C45, C64, C73, C75, C76: 0.1u; C_0603_1608Metric_Pad1.08x0.95mm_HandSolder
C24, C33, C36, C37, C40: 10u; C_0805_2012Metric_Pad1.18x1.45mm_HandSolder
C28, C29, C30, C31: 2.2u ESR<100m; C_0603_1608Metric_Pad1.08x0.95mm_HandSolder
C46, C77: 22u; C_0805_2012Metric_Pad1.18x1.45mm_HandSolder
C55: 4.7u ESR<100m; C_0603_1608Metric_Pad1.08x0.95mm_HandSolder
C56: 220pF; C_0603_1608Metric_Pad1.08x0.95mm_HandSolder
C57, C58: 10u ESR<20m; C_0805_2012Metric_Pad1.18x1.45mm_HandSolder
C59, C60: 12p; C_0603_1608Metric_Pad1.08x0.95mm_HandSolder
C61, C62: 15p; C_0603_1608Metric_Pad1.08x0.95mm_HandSolder
D1: SM712_SOT23; SOT-23
D2: GREEN; R_0805_2012Metric_Pad1.20x1.40mm_HandSolder
D3: YELLOW; R_0805_2012Metric_Pad1.20x1.40mm_HandSolder
D4: BAT54SW_115
D6: RED; R_0805_2012Metric_Pad1.20x1.40mm_HandSolder
FB1: MFBW1V1608-601-R; R_0603_1608Metric_Pad0.98x0.95mm_HandSolder
GND: TestPoint; TestPoint_Pad_1.0x1.0mm
H1, H2, H3, H4, H5, H7, H8, H9, H10, H11: MountingHole; MountingHole_3.2mm_M3_Pad_TopOnly
H7RST1: SW_Push; SW_SPST_PTS645Sx43SMTR92
H7_UART/SWD: Conn_02x05_Odd_Even; PinHeader_2x05_P2.54mm_Vertical
J1, J2: S6B-XH-A; JST_S6B-XH-A
J3: Conn_02x05_Odd_Even; PinHeader_2x05_P2.54mm_Vertical
J5: DF40C-100DS-0.4V_51_; HIROSE_DF40C-100DS-0.4V_51_
J6: DF40C-40DS-0.4V_51_; HIROSE_DF40C-40DS-0.4V_51_
JP1: Jumper_2_Open; PinHeader_1x02_P2.54mm_Vertical
L1: VLS252012CX-2R2M-1; IND_VLS252012CX-2R2M-1
MainClock1: ABM10W-24.0000MHZ-8-D1X-T3; XTAL_ABM10W-24.0000MHZ-8-D1X-T3
PROG: GREEN; R_0805_2012Metric_Pad1.20x1.40mm_HandSolder
R1: 120; R_1210_3225Metric_Pad1.30x2.65mm_HandSolder
R2, R3, R4, R5, R6, R7, R16, R25, R26, R27, R28, R29, R31, R32, R48, R49, R52, R53: 10k; R_0603_1608Metric_Pad0.98x0.95mm_HandSolder
R8, R9, R10, R11, R12, R17, R18, R22: 1k; R_0603_1608Metric_Pad0.98x0.95mm_HandSolder
R13, R20: 56k; R_0603_1608Metric_Pad0.98x0.95mm_HandSolder
R14, R19: 110k; R_0603_1608Metric_Pad0.98x0.95mm_HandSolder
R15, R21: 100k; R_0603_1608Metric_Pad0.98x0.95mm_HandSolder
R23, R24, R44, R50, R51: 4.7k; R_0603_1608Metric_Pad0.98x0.95mm_HandSolder
R30, R33, R34, R35, R36, R37, R38, R39, R40, R41, R42, R43, R45, R46, R47, R54, R55, R56, R57: 33; R_0603_1608Metric_Pad0.98x0.95mm_HandSolder
RN1, RN2, RN3, RN4, RN5, RN6, RN7, RN8, RN9, RN10: CAY16-330J4LF; 33ohmresarray
RS485: YELLOW; R_0805_2012Metric_Pad1.20x1.40mm_HandSolder
RTC1: ABS07-32.768KHZ-9-T; XTAL_ABS07-32.768KHZ-9-T
SW1: 3-1825010-8; SW6_3-1825010-8_TEC
U1: STM32H757IIT6; LQFP-176
U2: ADR4525BRZ-R7; R_8_ADI-M
U3: THVD1450D; D0008A_M
U4: STM32G071KBT6; LQFP-32-M
U5, U6: AP7361C-33Y5-13; SOT89-5_DIO-M
U7, U11: PTPS2117DRLR; SOT-5X3-8_DRL_TEX-M
U8: W25Q128JVSIQ TR; SOIC_208MIL_WIN-M
UH_OH: RED; R_0805_2012Metric_Pad1.20x1.40mm_HandSolder
USER: SW_Push; SW_SPST_PTS645Sx43SMTR92

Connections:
3V3MODULES: 3V3SoC.1, C45.1, C46.1, C72.1, C73.1, R19.1, R21.1, U7.2 (VOUT), U7.7 (VOUT), U11.3 (VIN1), U11.5 (MODE)
3V3PROGRAMMER: C23.1, C64.1, C74.1, C75.1, J1.1, J2.1, U11.6 (VIN2)
5VHPSoC: C33.1, C34.1, J5.2, J5.4, J5.98, J5.100, U5.1 (EN), U5.4 (IN)
5VHSSoC: C37.1, C38.1, J6.2, J6.4, U6.1 (EN), U6.4 (IN)
+3V3: 3V3.1, C1.1, C2.1, C3.1, C4.1, C5.1, C6.1, C7.1, C8.1, C9.1, C10.1, C11.1, C12.1, C13.1, C14.1, C15.1, C16.1, C17.1, C22.1, C24.1, C25.1, C32.1, C51.1, C54.1, C55.1, C63.1, C76.1, C77.1, FB1.2, H7_UART/SWD.1, J3.1, J3.6, J5.23, J5.24, J5.73, J5.74, J6.19, J6.20, R2.1, R5.1, R6.1, R16.2, R17.1, R18.1, R22.1, R23.1, R24.1, R25.1, R26.1, R27.1, R28.1, R29.1, R31.1, R32.1, R44.1, R48.1, R49.1, R50.1, R51.1, R52.1, R53.1, U1.7 (VDD), U1.8 (VBAT), U1.13 (VDD), U1.16 (VDDSMPS), U1.25 (VDD), U1.44 (VDD), U1.48 (VDD), U1.65 (VDD), U1.71 (VDD), U1.84 (VDD), U1.92 (VDD), U1.99 (VDD), U1.113 (VDD), U1.120 (VDD50USB), U1.121 (VDD33USB), U1.126 (VDD), U1.136 (VDD), U1.152 (VDD), U1.160 (VDD), U1.174 (PDR_ON), U1.176 (VDD), U2.2 (VIN), U3.8 (VCC), U4.4 (VDD), U8.8 (VCC), U11.2 (VOUT), U11.7 (VOUT)
/MCU2/40P_CONN/FDCAN_RX: J6.15, U1.143 (PD0)
/MCU2/40P_CONN/FDCAN_TX: J6.17, U1.144 (PD1)
/MCU2/40P_CONN/GPIO_PD7: R35.1, U1.150 (PD7)
/MCU2/40P_CONN/GPIO_PE0: R42.1, U1.170 (PE0)
/MCU2/40P_CONN/GPIO_PE1: R43.1, U1.171 (PE1)
/MCU2/40P_CONN/GPIO_PE3: R45.1, U1.2 (PE3)
/MCU2/40P_CONN/I2C1_SCL: J6.18, R23.2, U1.168 (PB8)
/MCU2/40P_CONN/I2C1_SDA: J6.14, R24.2, U1.169 (PB9)
/MCU2/40P_CONN/SDMMC1_CK: R30.1, U1.142 (PC12)
/MCU2/40P_CONN/SDMMC1_CMP: J6.23, R25.2, U1.145 (PD2)
/MCU2/40P_CONN/SDMMC1_D0: J6.5, R28.2, U1.124 (PC8)
/MCU2/40P_CONN/SDMMC1_D1: J6.3, R29.2, U1.125 (PC9)
/MCU2/40P_CONN/SDMMC1_D2: J6.7, R27.2, U1.140 (PC10)
/MCU2/40P_CONN/SDMMC1_D3: J6.9, R26.2, U1.141 (PC11)
/MCU2/40P_CONN/USART2_CTS: J6.25, R32.2, U1.146 (PD3)
/MCU2/40P_CONN/USART2_RTS: R33.1, U1.147 (PD4)
/MCU2/40P_CONN/USART2_RX: J6.33, R31.2, U1.149 (PD6)
/MCU2/40P_CONN/USART2_TX: R34.1, U1.148 (PD5)
/MCU2/100P_CONN/ADC_PA3: J5.80, U1.46 (PA3)
/MCU2/100P_CONN/ADC_PA6: J5.86, U1.51 (PA6)
/MCU2/100P_CONN/ADC_PB0: J5.88, U1.55 (PB0)
/MCU2/100P_CONN/ADC_PB1: J5.90, U1.56 (PB1)
/MCU2/100P_CONN/ADC_PC0: J5.34, U1.34 (PC0)
/MCU2/100P_CONN/DAC_ADC_PA4: J5.82, U1.49 (PA4)
/MCU2/100P_CONN/DAC_ADC_PA5: J5.84, U1.50 (PA5)
/MCU2/100P_CONN/GPIO_PB2: R54.1, U1.57 (PB2)
/MCU2/100P_CONN/GPIO_PE7: RN7.8, U1.67 (PE7)
/MCU2/100P_CONN/GPIO_PG0: RN7.6, U1.63 (PG0)
/MCU2/100P_CONN/GPIO_PG1: RN7.7, U1.66 (PG1)
/MCU2/QSPIMEM/QUADSPI_BK1_CLK: R57.1, U1.30 (PF10)
/MCU2/QSPIMEM/QUADSPI_BK1_IO0: U1.28 (PF8), U8.5 (DI(IO0))
/MCU2/QSPIMEM/QUADSPI_BK1_IO1: U1.29 (PF9), U8.2 (DO(IO1))
/MCU2/QSPIMEM/QUADSPI_BK1_IO2: U1.27 (PF7), U8.3 (/WP(IO2))
/MCU2/QSPIMEM/QUADSPI_BK1_IO3: U1.26 (PF6), U8.7 (/HOLD_/RESET)
BUSH7BOOT0: SW1.16, U4.27 (PB3)
BUSH7NRST: SW1.6, U4.17 (PB2)
BUSH7SWCLK: SW1.10, U4.16 (PB1)
BUSH7SWDIO: SW1.9, U4.15 (PB0)
BUSH7UARTRX: SW1.13, U4.32 (PB8)
BUSHH7UARTTX: SW1.3, U4.1 (PB9)
G0UARTRX: J3.8, U4.10 (PA3)
G0UARTTX: J3.7, U4.9 (PA2)
GND: 3V3HPSoC.1 (K), 3V3HSSoC.1 (K), C1.2, C2.2, C3.2, C4.2, C5.2, C6.2, C7.2, C8.2, C9.2, C10.2, C11.2, C12.2, C13.2, C14.2, C15.2, C16.2, C17.2, C18.2, C19.2, C20.2, C21.2, C22.2, C23.2, C24.2, C25.2, C26.2, C27.2, C28.2, C29.2, C30.2, C31.2, C32.2, C33.2, C34.2, C35.2, C36.2, C37.2, C38.2, C39.2, C40.2, C41.2, C42.2, C43.2, C44.2, C45.2, C46.2, C47.2, C48.2, C49.2, C51.2, C52.2, C54.2, C55.2, C56.2, C57.2, C58.2, C59.2, C60.2, C61.2, C62.2, C63.2, C64.2, C72.2, C73.2, C74.2, C75.2, C76.2, C77.2, D1.3 (common), GND.1, H7RST1.2, H7_UART/SWD.5, H7_UART/SWD.9, J1.4, J2.4, J3.3, J3.5, J3.9, J5.1, J5.6, J5.11, J5.16, J5.21, J5.26, J5.31, J5.36, J5.38, J5.40, J5.41, J5.42, J5.44, J5.46, J5.48, J5.50, J5.51, J5.52, J5.54, J5.56, J5.58, J5.60, J5.61, J5.62, J5.64, J5.66, J5.68, J5.70, J5.71, J5.72, J5.76, J5.81, J5.91, J6.1, J6.6, J6.11, J6.16, J6.21, J6.26, J6.31, J6.36, MainClock1.2 (GND), MainClock1.4 (GND__1), PROG.1 (K), R3.2, R4.2, R7.2, R13.2, R20.2, RS485.1 (K), U1.6 (VSS), U1.12 (VSS), U1.14 (VSSSMPS), U1.24 (VSS), U1.38 (VSSA), U1.45 (VSS), U1.47 (VSS), U1.64 (VSS), U1.70 (VSS), U1.81 (VSS), U1.83 (VSS), U1.93 (VSS), U1.100 (VSS), U1.105 (VSSDSI), U1.109 (VSSDSI), U1.112 (VSS), U1.119 (VSS), U1.134 (VSS), U1.137 (VSS), U1.151 (VSS), U1.159 (VSS), U1.173 (VSS), U2.4 (GND), U3.5 (GND), U4.5 (VSS), U5.2 (GND), U6.2 (GND), U7.1 (GND), U8.4 (GND), U11.1 (GND), UH_OH.1 (K), USER.2
GPIO_PG15: R41.1, U1.161 (PG15)
H7BOOT0: R4.1, SW1.17, U1.167 (BOOT0)
H7NRST: C26.1, D4.3, H7RST1.1, R5.2, U1.33 (NRST)
H7SWCLK: SW1.11, U1.138 (PA14)
H7SWDIO: R6.2, SW1.8, U1.132 (PA13)
H7SWO: H7_UART/SWD.6, U1.162 (PB3)
H7UARTRX: SW1.14, U1.129 (PA10)
H7UARTTX: SW1.2, U1.128 (PA9)
unnamed: 3V3HPSoC.2 (A), R11.2
unnamed: 3V3HSSoC.2 (A), R12.2
unnamed: C28.1, U1.172 (VCAP)
unnamed: C29.1, U1.133 (VCAP)
unnamed: C30.1, U1.80 (VCAP)
unnamed: D1.1 (A1), J1.2, J2.2, JP1.2 (B), U3.6 (A)
unnamed: D1.2 (A2), J1.3, J2.3, R1.2, U3.7 (B)
unnamed: D2.2 (A), R18.2
unnamed: D2.1 (K), U1.154 (PG10)
unnamed: D3.2 (A), R22.2
unnamed: D3.1 (K), U1.155 (PG11)
unnamed: D4.2, SW1.5
unnamed: D6.2 (A), R17.2
unnamed: D6.1 (K), U1.153 (PG9)
unnamed: H7_UART/SWD.2, SW1.7
unnamed: H7_UART/SWD.3, SW1.4
unnamed: H7_UART/SWD.4, SW1.12
unnamed: H7_UART/SWD.7, SW1.1
unnamed: H7_UART/SWD.8, SW1.15
unnamed: H7_UART/SWD.10, SW1.18
unnamed: J3.2, U4.24 (PA13)
unnamed: J3.4, R7.1, U4.25 (PA14-BOOT0)
unnamed: C27.1, J3.10, U4.6 (PF2-NRST)
unnamed: J5.45, RN1.4
unnamed: J5.47, RN1.3
unnamed: J5.49, RN1.2
unnamed: J5.53, RN1.1
unnamed: J5.55, RN4.8
unnamed: J5.57, RN4.7
unnamed: J5.59, RN4.6
unnamed: J5.63, RN4.5
unnamed: J5.87, RN7.1
unnamed: J5.89, RN7.2
unnamed: J5.92, R54.2
unnamed: J5.93, RN7.3
unnamed: J5.94, RN8.4
unnamed: J5.95, RN7.4
unnamed: J5.96, RN8.3
unnamed: J5.97, RN8.1
unnamed: J5.99, RN8.2
unnamed: J6.8, R45.2
unnamed: J6.10, R43.2
unnamed: J6.12, R42.2
unnamed: J6.13, R30.2
unnamed: J6.22, R41.2
unnamed: J6.24, R40.2
unnamed: J6.27, R33.2
unnamed: J6.28, R38.2
unnamed: J6.29, R34.2
unnamed: J6.35, R35.2
unnamed: J6.37, R39.2
unnamed: J6.39, R36.2
unnamed: J6.40, R37.2
unnamed: JP1.1 (A), R1.1
unnamed: PROG.2 (A), R10.2
unnamed: R9.2, RS485.2 (A)
unnamed: U1.156 (PG12), USER.1
unnamed: C31.1, C52.1, U1.101 (VCAPDSI), U1.102 (VDD12DSI), U1.108 (VDD12DSI)
unnamed: C18.1, C19.1, FB1.1, U1.40 (VDDA)
unnamed: C47.1, C48.1, C49.1, C57.1, C58.1, L1.1, U1.17 (VFBSMPS), U1.82 (VDDLDO), U1.135 (VDDLDO), U1.175 (VDDLDO)
unnamed: C56.1, L1.2, U1.15 (VLXSMPS)
unnamed: C20.1, C21.1, U1.39 (VREF+), U2.6 (VOUT)
unnamed: U3.4 (D), U4.19 (PA9)
unnamed: R3.1, U3.2 (RE_N), U3.3 (DE), U4.23 (PA12[PA10])
unnamed: R2.2, U3.1 (R), U4.21 (PA10)
unnamed: R8.1, U4.11 (PA4)
unnamed: R9.1, U4.12 (PA5)
unnamed: R10.1, U4.13 (PA6)
unnamed: C35.1, C36.1, C43.1, C44.1, R11.1, U5.5 (OUT), U7.6 (VIN2)
unnamed: C39.1, C40.1, C41.1, C42.1, R12.1, R14.1, R15.1, U6.5 (OUT), U7.3 (VIN1), U7.5 (MODE)
unnamed: R13.1, R14.2, U7.4 (PR1)
unnamed: R15.2, U7.8 (ST)
unnamed: R57.2, U8.6 (CLK)
unnamed: R19.2, R20.1, U11.4 (PR1)
unnamed: R21.2, U11.8 (ST)
unnamed: R8.2, UH_OH.2 (A)
OSC32_IN: C62.1, RTC1.1, U1.10 (PC14-OSC32_IN)
OSC32_OUT: C61.1, RTC1.2, U1.11 (PC15-OSC32_OUT)
OSC_IN: C60.1, MainClock1.1, U1.31 (PH0-OSC_IN)
OSC_OUT: C59.1, MainClock1.3, U1.32 (PH1-OSC_OUT)
PA1: R38.1, U1.42 (PA1)
PA2: J6.30, R44.2, U1.43 (PA2)
PA7: J6.32, U1.52 (PA7)
PB10: R16.1, U1.78 (PB10), U8.1 (/CS)
PB11: R39.1, U1.79 (PB11)
PC1: R40.1, U1.35 (PC1)
PC4: J6.34, U1.53 (PC4)
PC5: J6.38, U1.54 (PC5)
PD8: RN1.8, U1.89 (PD8)
PD9: RN1.7, U1.90 (PD9)
PD10: RN1.6, U1.91 (PD10)
PD11: RN1.5, U1.94 (PD11)
PF11: RN8.5, U1.58 (PF11)
PF12: RN8.6, U1.59 (PF12)
PF13: RN8.7, U1.60 (PF13)
PF14: RN8.8, U1.61 (PF14)
PF15: RN7.5, U1.62 (PF15)
PG13: R36.1, U1.157 (PG13)
PG14: R37.1, U1.158 (PG14)
SPI2_MISO: RN4.2, U1.87 (PB14)
SPI2_MOSI: RN4.1, U1.88 (PB15)
SPI2_NSS: R53.2, RN4.4, U1.85 (PB12)
SPI2_SCK: RN4.3, U1.86 (PB13)

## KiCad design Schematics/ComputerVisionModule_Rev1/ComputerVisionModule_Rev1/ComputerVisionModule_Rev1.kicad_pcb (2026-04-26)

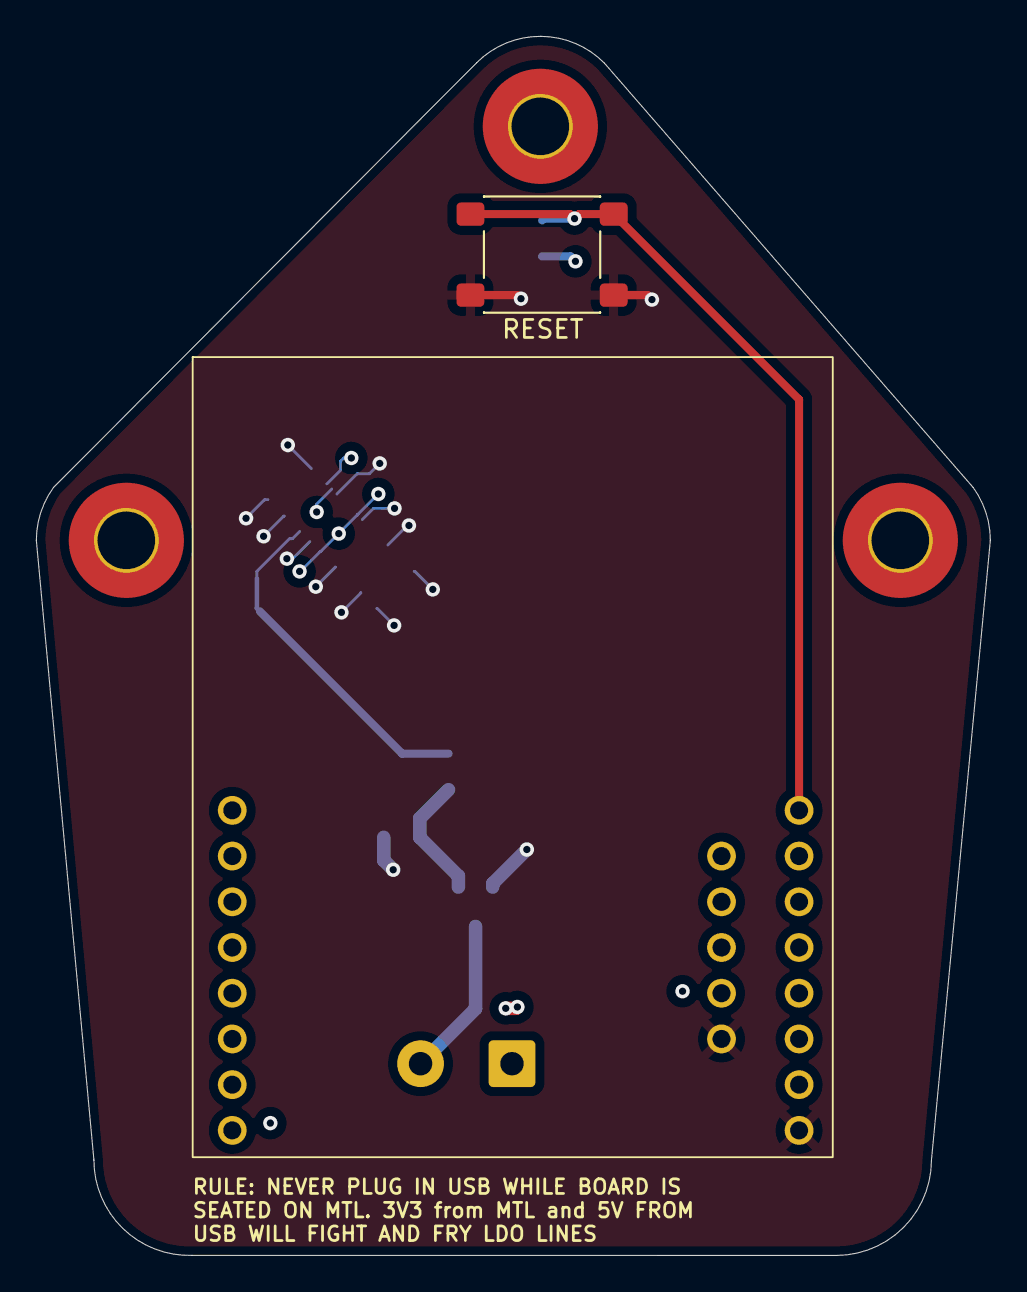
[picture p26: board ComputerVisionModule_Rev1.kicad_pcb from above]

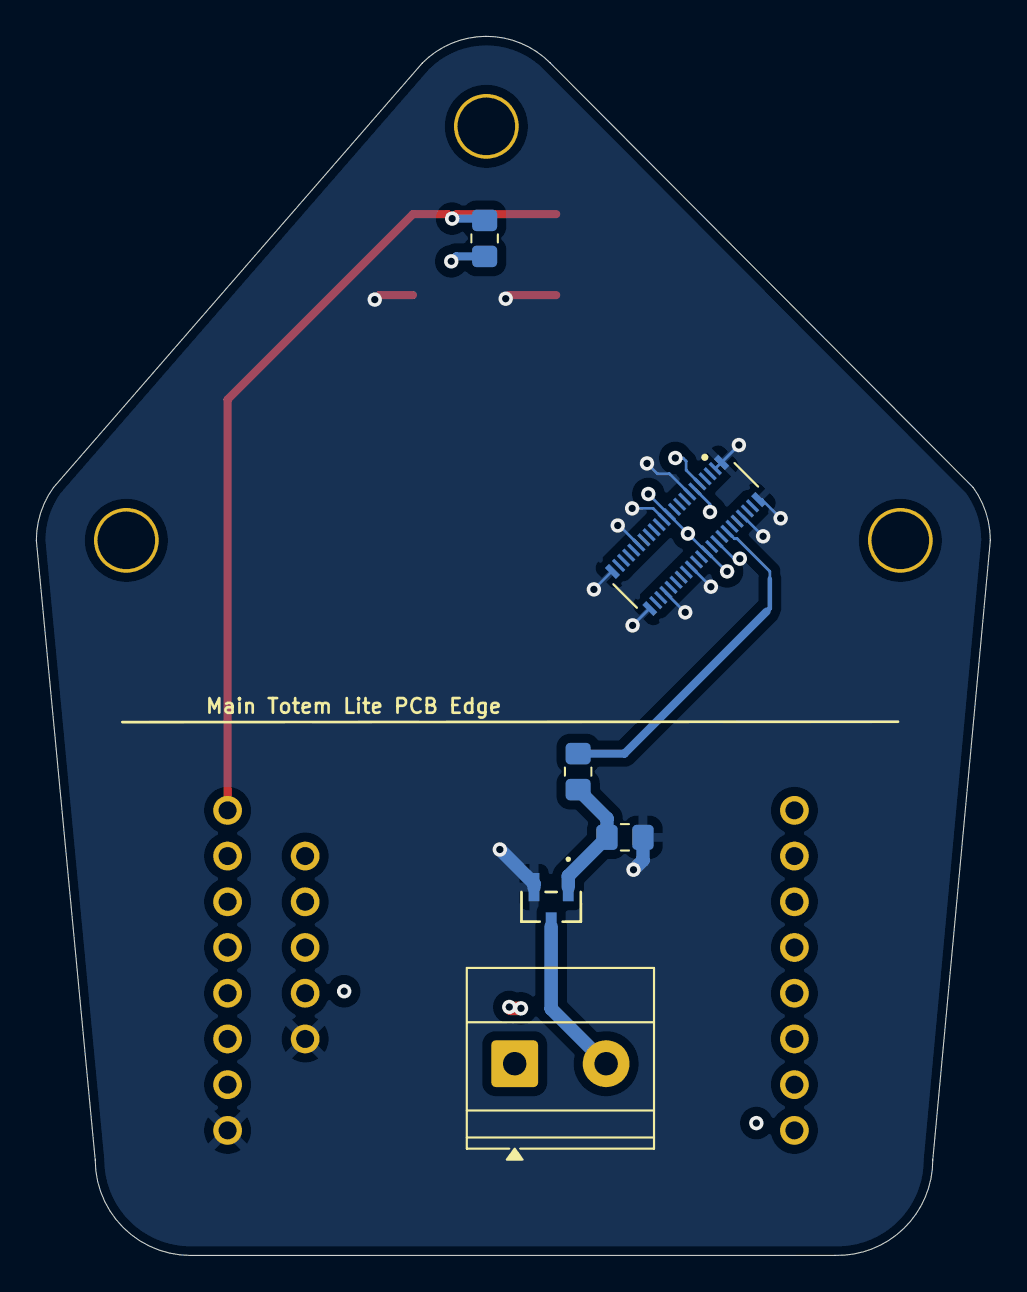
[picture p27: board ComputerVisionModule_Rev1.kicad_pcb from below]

Board: 4 copper layers, 53.0 x 67.7 mm, 11 parts (6 on the bottom side), 8 nets.

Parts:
H1, H2, H3: MountingHole; MountingHole_3.2mm_M3_Pad_TopOnly
J1: DF40C-40DP-0.4V_51_; HRS_DF40C-40DP-0.4V_51_
J2: Screw_Terminal_01x02; TerminalBlock_Phoenix_MKDS-1,5-2-5.08_1x02_P5.08mm_Horizont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
R1, R3: 10k; R_0805_2012Metric_Pad1.20x1.40mm_HandSolder
R2: 100; R_0805_2012Metric_Pad1.20x1.40mm_HandSolder
SW1: SW_Push; SW_SPST_PTS645Sx43SMTR92
U1: OPENMV4_H7
U2: BSS138; SOT-23_3L_ONS-M

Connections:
+3V3: J1.19, J1.20, J2.1, R1.1, U1.1 (3V3), U1.7 (3V3)
GND: J1.1, J1.6, J1.11, J1.16, J1.21, J1.26, J1.31, J1.36, J1.S1 (SHIELD), J1.S2 (SHIELD__1), J1.S3 (SHIELD__2), J1.S4 (SHIELD__3), R3.2, SW1.2, U1.3 (GND), U1.5 (GND), U2.2 (S)
unnamed: J1.12, R2.1
unnamed: J2.2, U2.3 (D)
unnamed: R1.2, SW1.1, U1.6 (RST)
unnamed: J1.7, U1.4 (RX)
unnamed: J1.9, U1.2 (TX)
unnamed: R2.2, R3.1, U2.1 (G)

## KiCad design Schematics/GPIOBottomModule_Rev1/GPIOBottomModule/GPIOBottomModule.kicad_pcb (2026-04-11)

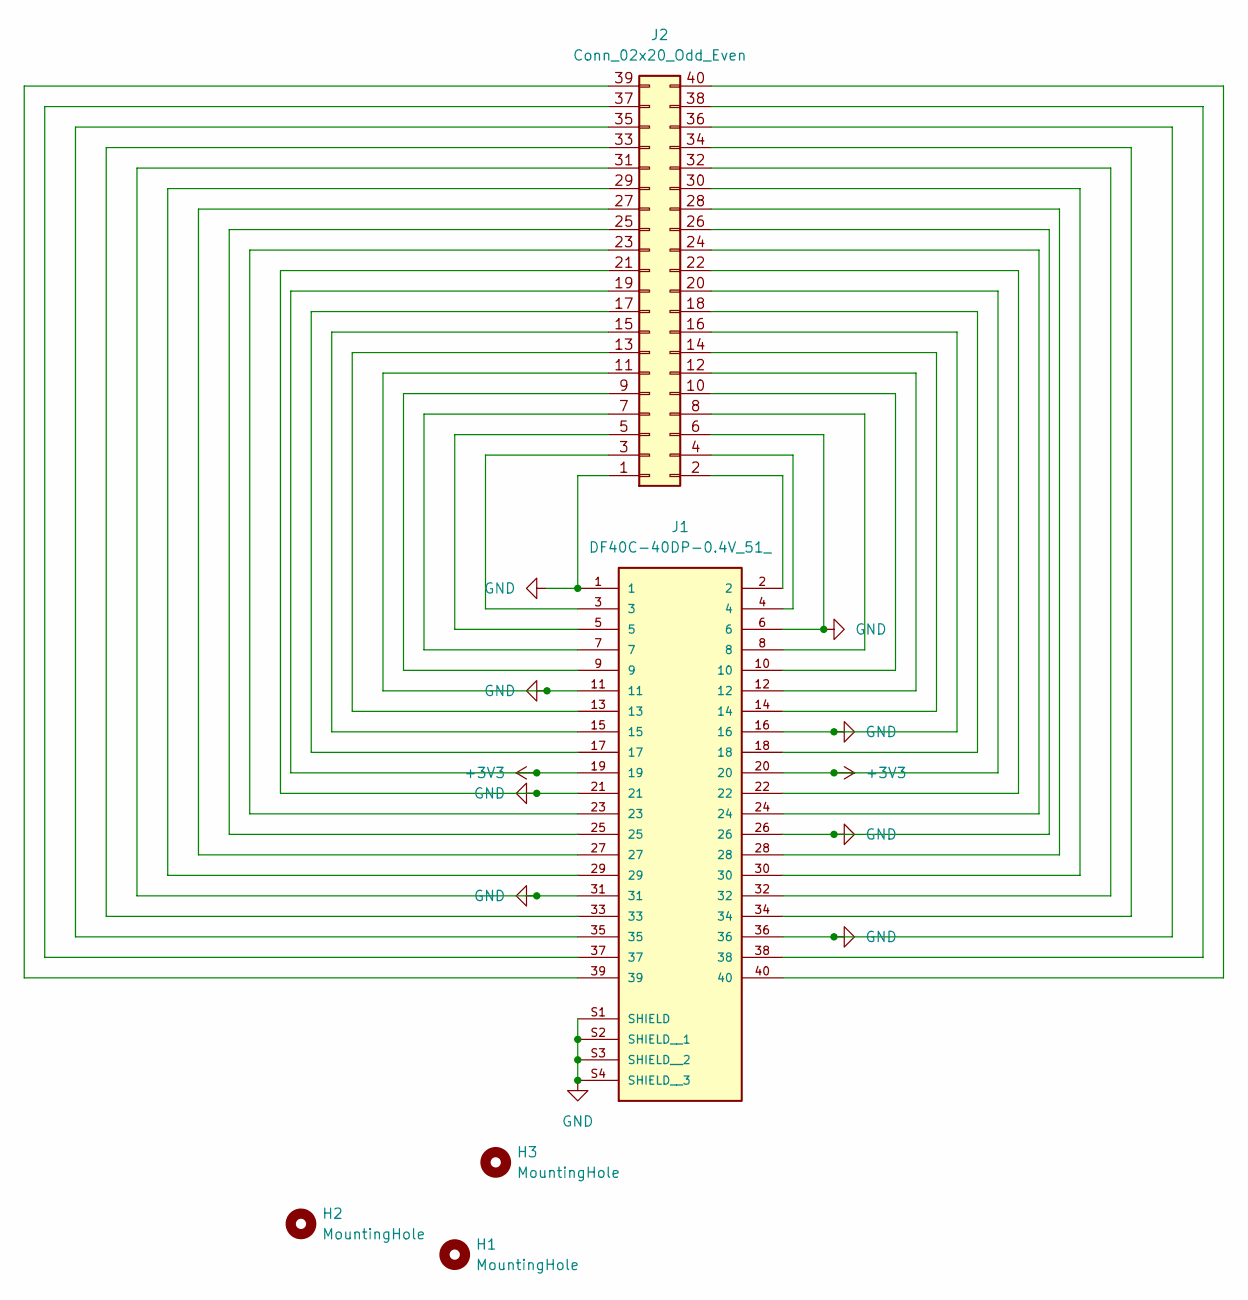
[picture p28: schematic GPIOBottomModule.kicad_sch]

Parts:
H1, H2, H3: MountingHole; MountingHole_3.2mm_M3_Pad_TopOnly
J1: DF40C-40DP-0.4V_51_; HRS_DF40C-40DP-0.4V_51_
J2: Conn_02x20_Odd_Even; PinHeader_2x20_P2.54mm_Vertical

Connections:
+3V3: J1.19, J1.20, J2.19, J2.20
GND: J1.1, J1.6, J1.11, J1.16, J1.21, J1.26, J1.31, J1.36, J1.S1 (SHIELD), J1.S2 (SHIELD__1), J1.S3 (SHIELD__2), J1.S4 (SHIELD__3), J2.1, J2.6, J2.11, J2.16, J2.21, J2.26, J2.31, J2.36
unnamed: J1.2, J2.2
unnamed: J1.3, J2.3
unnamed: J1.4, J2.4
unnamed: J1.5, J2.5
unnamed: J1.7, J2.7
unnamed: J1.8, J2.8
unnamed: J1.9, J2.9
unnamed: J1.10, J2.10
unnamed: J1.12, J2.12
unnamed: J1.13, J2.13
unnamed: J1.14, J2.14
unnamed: J1.15, J2.15
unnamed: J1.17, J2.17
unnamed: J1.18, J2.18
unnamed: J1.22, J2.22
unnamed: J1.23, J2.23
unnamed: J1.24, J2.24
unnamed: J1.25, J2.25
unnamed: J1.27, J2.27
unnamed: J1.28, J2.28
unnamed: J1.29, J2.29
unnamed: J1.30, J2.30
unnamed: J1.32, J2.32
unnamed: J1.33, J2.33
unnamed: J1.34, J2.34
unnamed: J1.35, J2.35
unnamed: J1.37, J2.37
unnamed: J1.38, J2.38
unnamed: J1.39, J2.39
unnamed: J1.40, J2.40

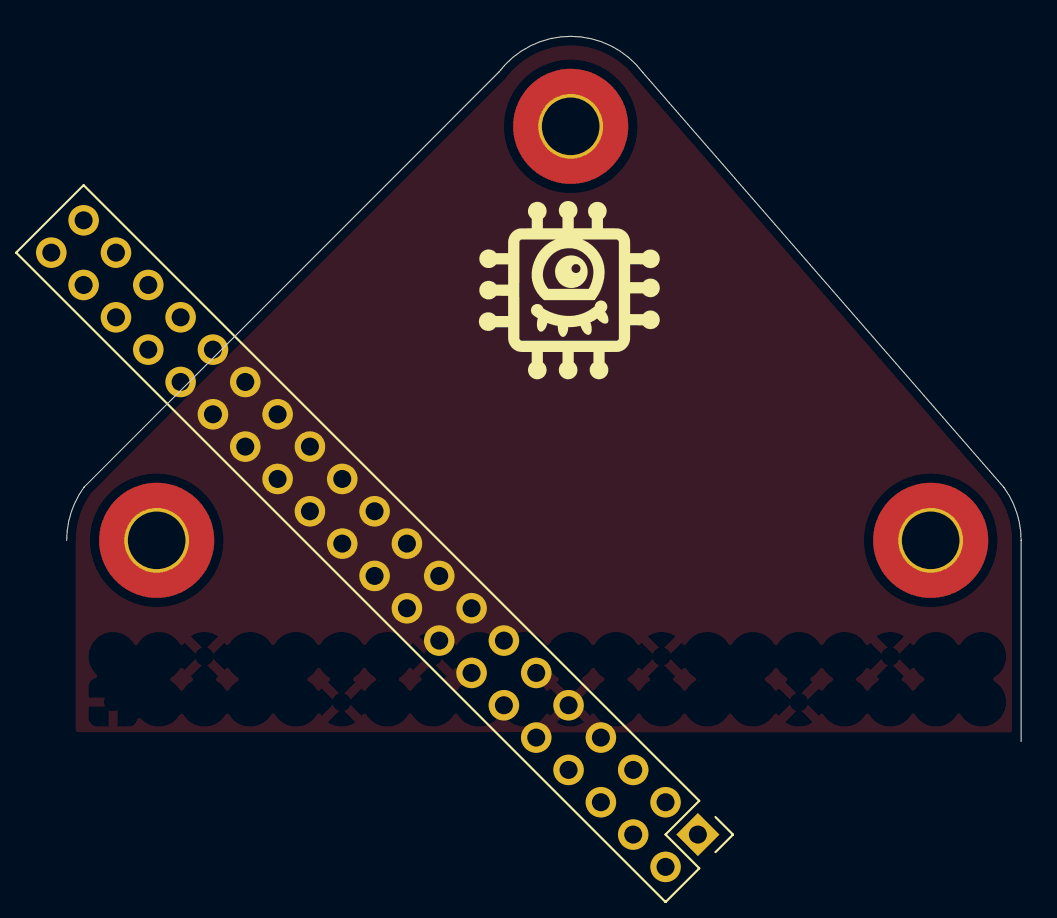
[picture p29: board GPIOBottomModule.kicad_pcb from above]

Board: 4 copper layers, 53.0 x 39.2 mm, 5 parts (1 on the bottom side), 32 nets.

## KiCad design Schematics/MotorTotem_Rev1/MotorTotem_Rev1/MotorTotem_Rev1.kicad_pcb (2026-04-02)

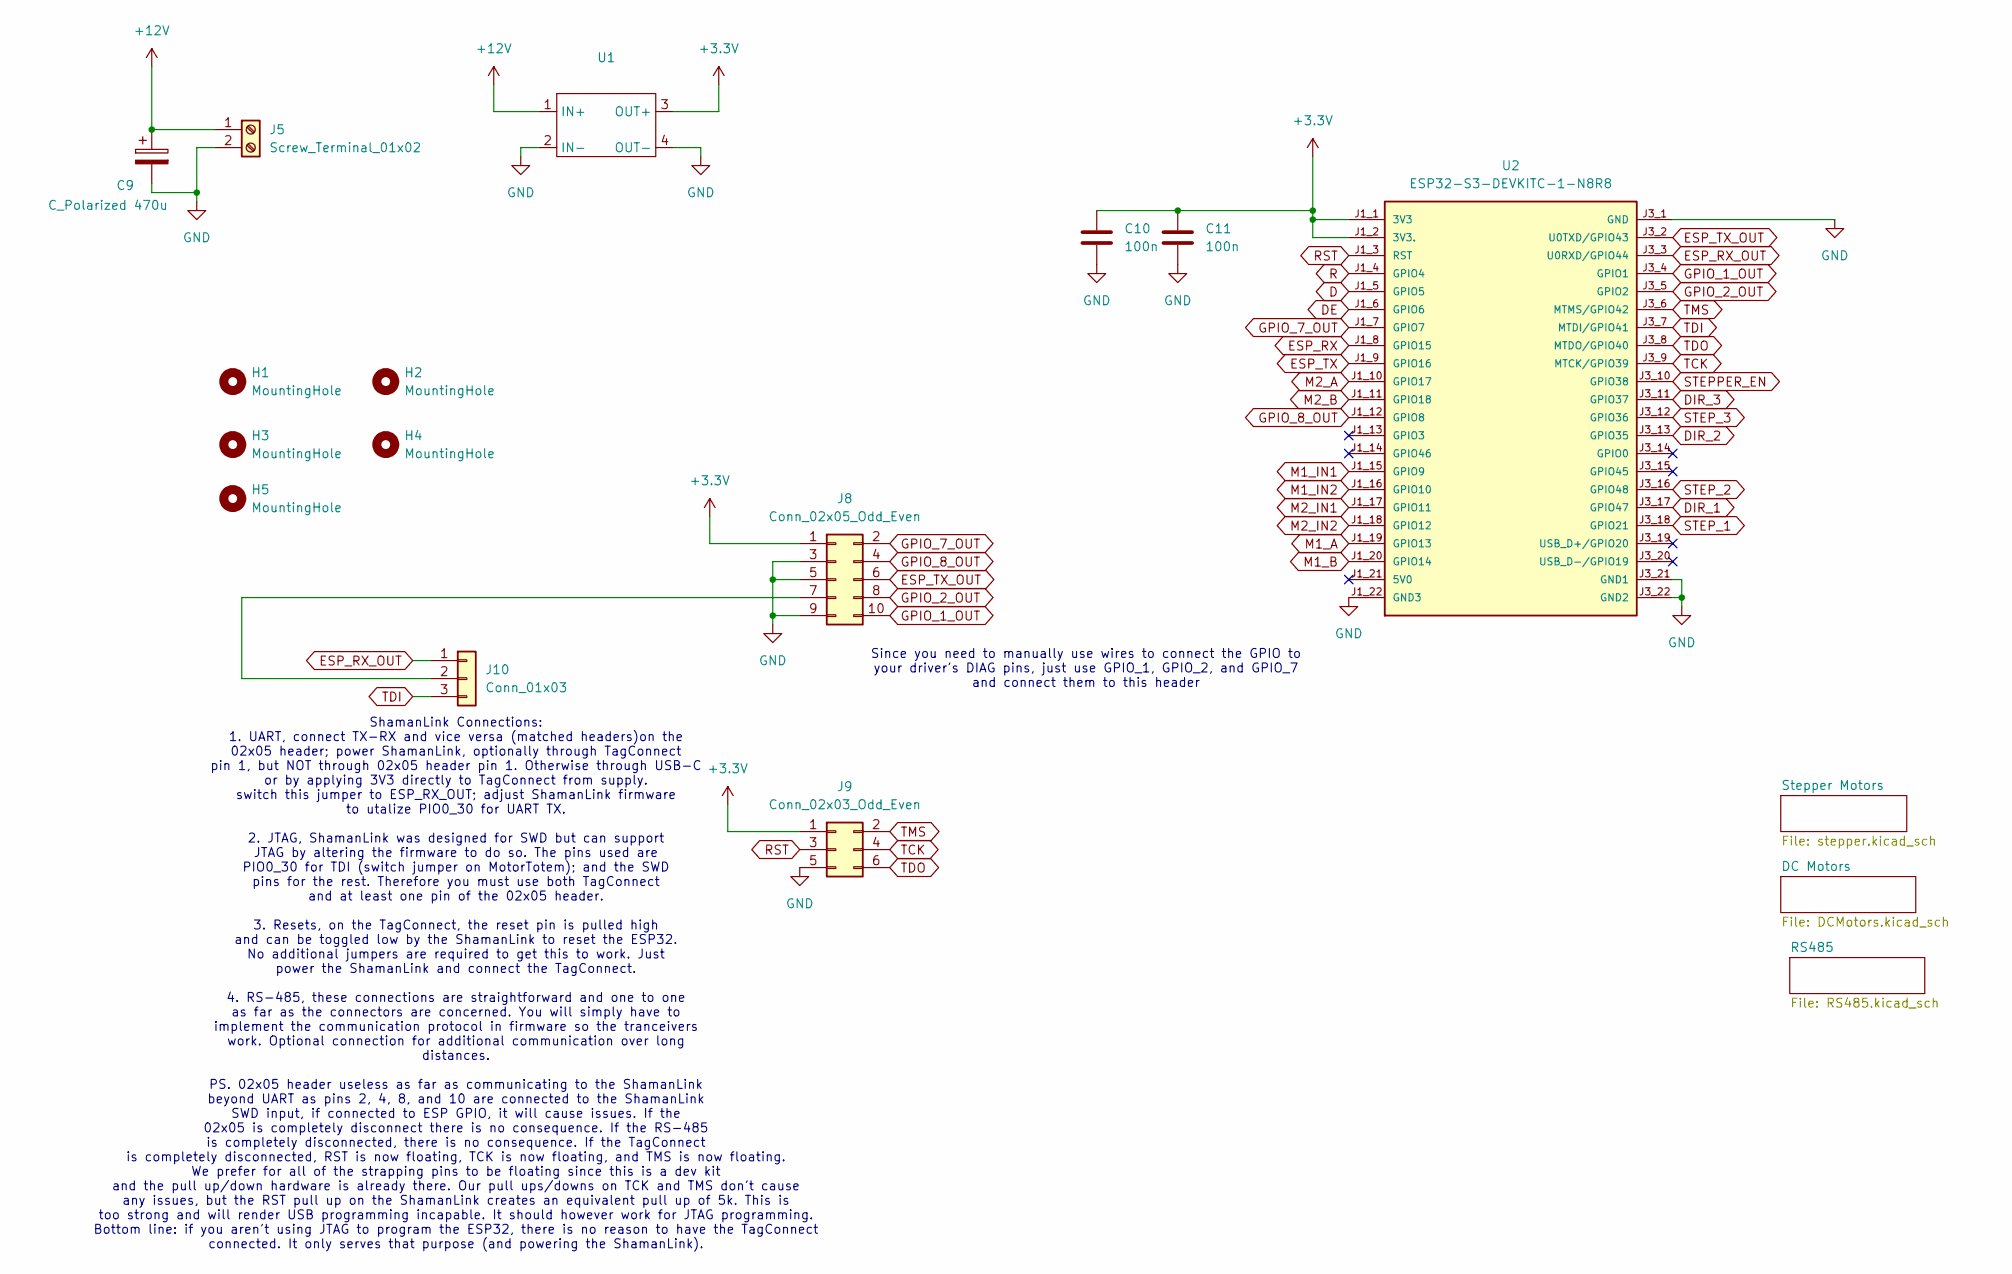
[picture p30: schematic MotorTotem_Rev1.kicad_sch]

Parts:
C9: C_Polarized 470u; CP_Radial_D6.3mm_P2.50mm
C10, C11: 100n; C_0805_2012Metric_Pad1.18x1.45mm_HandSolder
H1, H2, H3, H4, H5: MountingHole; MountingHole_2.5mm_Pad_TopOnly
J5: Screw_Terminal_01x02; TerminalBlock_Phoenix_MKDS-1,5-2-5.08_1x02_P5.08mm_Horizont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
J8: Conn_02x05_Odd_Even; PinHeader_2x05_P2.54mm_Vertical
J9: Conn_02x03_Odd_Even; PinHeader_2x03_P2.54mm_Vertical
J10: Conn_01x03; PinHeader_1x03_P2.54mm_Vertical
U1: LM2596BuckBoost
U2: ESP32-S3-DEVKITC-1-N8R8

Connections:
+3.3V: C10.1, C11.1, J8.1, J9.1, U1.3 (OUT+), U2.J1_1 (3V3), U2.J1_2 (3V3.); also elsewhere on the board
+12V: C9.1, J5.1, U1.1 (IN+); also elsewhere on the board
D: U2.J1_5 (GPIO5); also elsewhere on the board
DE: U2.J1_6 (GPIO6); also elsewhere on the board
DIR_1: U2.J3_17 (GPIO47); also elsewhere on the board
DIR_2: U2.J3_13 (GPIO35); also elsewhere on the board
DIR_3: U2.J3_11 (GPIO37); also elsewhere on the board
ESP_RX: U2.J1_8 (GPIO15); also elsewhere on the board
ESP_RX_OUT: J10.1, U2.J3_3 (U0RXD/GPIO44)
ESP_TX: U2.J1_9 (GPIO16); also elsewhere on the board
ESP_TX_OUT: J8.6, U2.J3_2 (U0TXD/GPIO43)
GND: C9.2, C10.2, C11.2, J5.2, J8.3, J8.5, J8.9, J9.5, U1.2 (IN-), U1.4 (OUT-), U2.J1_22 (GND3), U2.J3_1 (GND), U2.J3_21 (GND1), U2.J3_22 (GND2); also elsewhere on the board
GPIO_1_OUT: J8.10, U2.J3_4 (GPIO1)
GPIO_2_OUT: J8.8, U2.J3_5 (GPIO2)
GPIO_7_OUT: J8.2, U2.J1_7 (GPIO7)
GPIO_8_OUT: J8.4, U2.J1_12 (GPIO8)
M1_A: U2.J1_19 (GPIO13); also elsewhere on the board
M1_B: U2.J1_20 (GPIO14); also elsewhere on the board
M1_IN1: U2.J1_15 (GPIO9); also elsewhere on the board
M1_IN2: U2.J1_16 (GPIO10); also elsewhere on the board
M2_A: U2.J1_10 (GPIO17); also elsewhere on the board
M2_B: U2.J1_11 (GPIO18); also elsewhere on the board
M2_IN1: U2.J1_17 (GPIO11); also elsewhere on the board
M2_IN2: U2.J1_18 (GPIO12); also elsewhere on the board
unnamed: J8.7, J10.2
R: U2.J1_4 (GPIO4); also elsewhere on the board
RST: J9.3, U2.J1_3 (RST)
STEPPER_EN: U2.J3_10 (GPIO38); also elsewhere on the board
STEP_1: U2.J3_18 (GPIO21); also elsewhere on the board
STEP_2: U2.J3_16 (GPIO48); also elsewhere on the board
STEP_3: U2.J3_12 (GPIO36); also elsewhere on the board
TCK: J9.4, U2.J3_9 (MTCK/GPIO39)
TDI: J10.3, U2.J3_7 (MTDI/GPIO41)
TDO: J9.6, U2.J3_8 (MTDO/GPIO40)
TMS: J9.2, U2.J3_6 (MTMS/GPIO42)

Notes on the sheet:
Since you need to manually use wires to connect the GPIO to your driver's DIAG pins, just use GPIO_1, GPIO_2, and GPIO_7 and connect them to this header
ShamanLink Connections: 1. UART, connect TX-RX and vice versa (matched headers)on the 02x05 header; power ShamanLink, optionally through TagConnect pin 1, but NOT through 02x05 header pin 1. Otherwise through USB-C or by applying 3V3 directly to TagConnect from supply. switch this jumper to ESP_RX_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

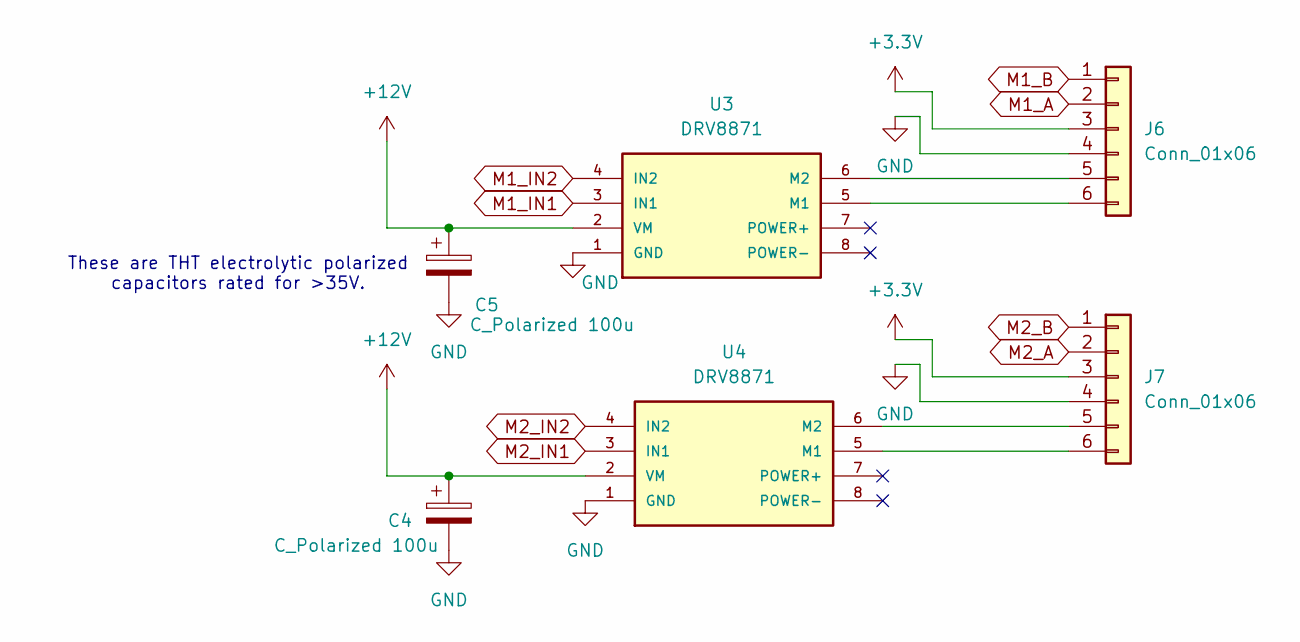
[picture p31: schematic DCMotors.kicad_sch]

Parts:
C4, C5: C_Polarized 100u; CP_Radial_D6.3mm_P2.50mm
J6, J7: Conn_01x06; PinHeader_1x06_P2.54mm_Vertical
U3, U4: DRV8871

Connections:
+3.3V: J6.3, J7.3; also elsewhere on the board
+12V: C4.1, C5.1, U3.2 (VM), U4.2 (VM); also elsewhere on the board
GND: C4.2, C5.2, J6.4, J7.4, U3.1 (GND), U4.1 (GND); also elsewhere on the board
M1_A: J6.2; also elsewhere on the board
M1_B: J6.1; also elsewhere on the board
M1_IN1: U3.3 (IN1); also elsewhere on the board
M1_IN2: U3.4 (IN2); also elsewhere on the board
M2_A: J7.2; also elsewhere on the board
M2_B: J7.1; also elsewhere on the board
M2_IN1: U4.3 (IN1); also elsewhere on the board
M2_IN2: U4.4 (IN2); also elsewhere on the board
unnamed: J6.5, U3.6 (M2)
unnamed: J6.6, U3.5 (M1)
unnamed: J7.5, U4.6 (M2)
unnamed: J7.6, U4.5 (M1)

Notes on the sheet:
These are THT electrolytic polarized capacitors rated for >35V.


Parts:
C1, C3: 0.1uF; C_0805_2012Metric_Pad1.18x1.45mm_HandSolder
C2: 10uF; C_0805_2012Metric_Pad1.18x1.45mm_HandSolder
D1: SM712_SOT23; SOT-23
J1: S6B-XH-A; JST_S6B-XH-A
R1: 120; R_1206_3216Metric_Pad1.30x1.75mm_HandSolder
R2, R3: 10k; R_0805_2012Metric_Pad1.20x1.40mm_HandSolder
U8: THVD1450D; D0008A_M

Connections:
+3.3V: C1.1, C2.1, C3.1, J1.1, R2.1, U8.8 (VCC); also elsewhere on the board
D: U8.4 (D); also elsewhere on the board
DE: R3.1, U8.2 (RE_N), U8.3 (DE); also elsewhere on the board
GND: C1.2, C2.2, C3.2, D1.3 (common), J1.4, R3.2, U8.5 (GND); also elsewhere on the board
unnamed: D1.1 (A1), J1.2, R1.2, U8.6 (A)
unnamed: D1.2 (A2), J1.3, R1.1, U8.7 (B)
R: R2.2, U8.1 (R); also elsewhere on the board


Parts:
C6, C7, C8: C_Polarized 100u; CP_Radial_D6.3mm_P2.50mm
C12, C13, C14: 100n; C_0805_2012Metric_Pad1.18x1.45mm_HandSolder
J2, J3, J4: Conn_01x04; PinHeader_1x04_P2.54mm_Vertical
R4: 1k; R_0805_2012Metric_Pad1.20x1.40mm_HandSolder
U5, U6, U7: TMC2209_SILENTSTEPSTICK; MODULE_TMC2209_SILENTSTEPSTICK; PARTREV 1.20

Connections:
+3.3V: C12.1, C13.1, C14.1, U5.2 (VIO), U6.2 (VIO), U6.15 (MS1), U7.2 (VIO), U7.14 (MS2); also elsewhere on the board
+12V: C6.1, C7.1, C8.1, U5.8 (VM), U6.8 (VM), U7.8 (VM); also elsewhere on the board
DIR_1: U5.9 (DIR); also elsewhere on the board
DIR_2: U6.9 (DIR); also elsewhere on the board
DIR_3: U7.9 (DIR); also elsewhere on the board
ESP_RX: R4.2, U5.12 (UART), U6.12 (UART), U7.12 (UART); also elsewhere on the board
ESP_TX: R4.1; also elsewhere on the board
GND: C6.2, C7.2, C8.2, C12.2, C13.2, C14.2, U5.1 (GND), U5.7 (GND), U5.14 (MS2), U5.15 (MS1), U6.1 (GND), U6.7 (GND), U6.14 (MS2), U7.1 (GND), U7.7 (GND), U7.15 (MS1); also elsewhere on the board
unnamed: J2.1, U5.4 (M1A)
unnamed: J2.2, U5.3 (M1B)
unnamed: J2.3, U5.5 (M2A)
unnamed: J2.4, U5.6 (M2B)
unnamed: J3.1, U6.4 (M1A)
unnamed: J3.2, U6.3 (M1B)
unnamed: J3.3, U6.5 (M2A)
unnamed: J3.4, U6.6 (M2B)
unnamed: J4.1, U7.4 (M1A)
unnamed: J4.2, U7.3 (M1B)
unnamed: J4.3, U7.5 (M2A)
unnamed: J4.4, U7.6 (M2B)
STEPPER_EN: U5.16 (~EN), U6.16 (~EN), U7.16 (~EN); also elsewhere on the board
STEP_1: U5.10 (STEP); also elsewhere on the board
STEP_2: U6.10 (STEP); also elsewhere on the board
STEP_3: U7.10 (STEP); also elsewhere on the board

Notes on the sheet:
These are THT electrolytic polarized capacitors rated for >35V.


Board: 4 copper layers, 137.8 x 98.3 mm, 42 parts (0 on the bottom side), 53 nets.

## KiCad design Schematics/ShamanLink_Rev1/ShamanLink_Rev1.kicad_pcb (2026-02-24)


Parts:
C3: 10nF; C_0805_2012Metric_Pad1.18x1.45mm_HandSolder
C5, C33: 47pF; C_0805_2012Metric_Pad1.18x1.45mm_HandSolder
C6, C8: 22uF; C_1206_3216Metric_Pad1.33x1.80mm_HandSolder
C7: 100nF; C_0805_2012Metric_Pad1.18x1.45mm_HandSolder
C9, C10, C11, C12, C15, C29, C30, C31, C35, C41: 0.1uF; C_0805_2012Metric_Pad1.18x1.45mm_HandSolder
C13, C32, C34: 10uF; C_0805_2012Metric_Pad1.18x1.45mm_HandSolder
C14: 1uF; C_0805_2012Metric_Pad1.18x1.45mm_HandSolder
C36: 4.7nF; C_0805_2012Metric_Pad1.18x1.45mm_HandSolder
CR4: USBLC6-2SC6; SOT23-6L_STM-M
F1: 1206L075/13.2WR; 1206LSeries_LTF-M
FB1, FB2, FB3, FB4, FB5: MFBW1V1608-601-R; R_0603_1608Metric_Pad0.98x0.95mm_HandSolder
J6: USB4105-GF-A; GCT_USB4105-GF-A; PARTREV B4
L1: 4.7uH CDRH2D11NP-4R7NC; Inductor_Sumida_CDRH2D11
L2: DLW21SN900HQ2L; IND_DLW21S_0805_MUR-M
R1, R2: 5.1kR; R_0805_2012Metric_Pad1.20x1.40mm_HandSolder
R3: 10kR; R_0805_2012Metric_Pad1.20x1.40mm_HandSolder
R4: 20kR; R_0805_2012Metric_Pad1.20x1.40mm_HandSolder
R33: 1M; R_0805_2012Metric_Pad1.20x1.40mm_HandSolder
U1: LPC55S69JBD64K; HTQFP64_SOT855-5_NXP-M

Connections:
+3.3V: C9.1, C10.1, C11.1, C12.1, C13.1, C14.1, C29.1, C31.1, C32.1, FB1.1, FB2.2, U1.8 (VDD), U1.16 (VDD), U1.27 (USB1_3V3), U1.43 (VDD), U1.54 (VDD), U1.61 (USB0_3V3); also elsewhere on the board
+3.3VA: C15.1, FB1.2, U1.9 (VDDA), U1.10 (VREFP)
+5V: F1.1, R3.1; also elsewhere on the board
CLOCK32M_N: U1.19 (XTAL32M_N); also elsewhere on the board
CLOCK32M_P: U1.20 (XTAL32M_P); also elsewhere on the board
GND: C3.2, C5.2, C6.2, C7.2, C8.2, C9.2, C10.2, C11.2, C12.2, C13.2, C29.2, C30.2, C31.2, C32.2, C33.2, C34.2, C35.2, C36.2, C41.2, CR4.2, FB3.2, FB5.2, J6.A1_B12 (GND), J6.B1_A12 (GND__1), R1.2, R2.2, R4.2, R33.2, U1.22 (USB1_VSS), U1.26 (USB1_VSS), U1.30 (VSS_DCDC), U1.34 (XTAL32K_P), U1.64 (USB0_VSS), U1.EPAD (VSS); also elsewhere on the board
GNDA: C14.2, C15.2, FB5.1, U1.11 (VSSA)
unnamed: CR4.4, L2.4
unnamed: CR4.6, L2.1
unnamed: F1.2, FB4.2
unnamed: J6.A5 (CC1), R1.1
unnamed: J6.B5 (CC2), R2.1
unnamed: CR4.3, J6.A7 (DN1), J6.B7 (DN2)
unnamed: CR4.1, J6.A6 (DP1), J6.B6 (DP2)
unnamed: C36.1, FB3.1, J6.SH1 (SHELL_GND), J6.SH2 (SHELL_GND__1), J6.SH3 (SHELL_GND__2), J6.SH4 (SHELL_GND__3), R33.1
unnamed: C3.1, C34.1, CR4.5, FB4.1, J6.A4_B9 (VBUS), J6.B4_A9 (VBUS__1)
unnamed: C6.1, C30.1, C33.1, L1.1, U1.28 (VDD_PMU), U1.29 (FB)
unnamed: L1.2, U1.31 (LX)
unnamed: L2.3, U1.24 (USB1_DM)
unnamed: L2.2, U1.23 (USB1_DP)
unnamed: C35.1, R3.2, R4.1, U1.25 (USB1_VBUS)
unnamed: C5.1, C7.1, C8.1, FB2.1, U1.32 (VBAT_DCDC), U1.33 (VBAT_PMU)
PIO0_7: U1.1 (PIO0_7); also elsewhere on the board
PIO0_8: U1.17 (PIO0_8); also elsewhere on the board
PIO0_13: U1.46 (PIO0_13); also elsewhere on the board
PIO0_14: U1.47 (PIO0_14); also elsewhere on the board
PIO0_20: U1.48 (PIO0_20); also elsewhere on the board
PIO0_21: U1.49 (PIO0_21); also elsewhere on the board
PIO0_24: U1.45 (PIO0_24); also elsewhere on the board
PIO0_25: U1.51 (PIO0_25); also elsewhere on the board
PIO0_29: U1.59 (PIO0_29); also elsewhere on the board
PIO0_30: U1.60 (PIO0_30); also elsewhere on the board
PIO0_31: U1.15 (PIO0_31/ADC0_3); also elsewhere on the board
PIO1_0: U1.4 (PIO1_0/ADC0_11); also elsewhere on the board
PIO1_1: U1.39 (PIO1_1/WAKEUP); also elsewhere on the board
PIO1_2: U1.41 (PIO1_2); also elsewhere on the board
PIO1_3: U1.42 (PIO1_3); also elsewhere on the board
PRESET: U1.21 (RESETN); also elsewhere on the board
ProISP: U1.56 (PIO0_5/TDI); also elsewhere on the board
ProRESET: C41.1, U1.36 (PIO0_0/ACMP0_A); also elsewhere on the board
ProSWDCLK: U1.6 (PIO0_11/ADC0_9); also elsewhere on the board
ProSWDIO: U1.5 (PIO0_12/ADC0_10); also elsewhere on the board
RS485RXLED: U1.3 (PIO0_17); also elsewhere on the board
RS485TXLED: U1.2 (PIO0_1); also elsewhere on the board
SDLED: U1.14 (PIO0_15/ADC0_2); also elsewhere on the board
SWD_CLK: U1.50 (PIO0_22); also elsewhere on the board
SWD_IO: U1.52 (PIO0_2/TRST); also elsewhere on the board
SWO: U1.53 (PIO0_3/TCK); also elsewhere on the board


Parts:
C42: 0.1uF; C_0805_2012Metric_Pad1.18x1.45mm_HandSolder
J5: Conn_ARM_SWD_TagConnect_TC2030-NL; Tag-Connect_TC2030-IDC-NL_2x03_P1.27mm_Vertical
R18, R19, R20, R38: 33; R_0805_2012Metric_Pad1.20x1.40mm_HandSolder
R35, R36, R37: 10k; R_0805_2012Metric_Pad1.20x1.40mm_HandSolder

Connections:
3.3VTARGET: J5.1 (VCC), R35.1, R37.1; also elsewhere on the board
GND: C42.2, J5.5 (GND), R36.2; also elsewhere on the board
unnamed: J5.4 (SWCLK), R19.1
unnamed: J5.2 (SWDIO), R18.1
unnamed: J5.6 (SWO), R38.1
unnamed: C42.1, J5.3 (~RESET), R20.1, R37.2
PIO0_21: R20.2; also elsewhere on the board
SWD_CLK: R19.2, R36.1; also elsewhere on the board
SWD_IO: R18.2, R35.2; also elsewhere on the board
SWO: R38.2; also elsewhere on the board

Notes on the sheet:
No need to implement these pull up and pull down resistors on the target board since they are already implemented here.


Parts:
3V3TARGET1: GREEN; LED_0805_2012Metric_Pad1.15x1.40mm_HandSolder
3V3USB1: YELLOW; LED_0805_2012Metric_Pad1.15x1.40mm_HandSolder
5V1: BLUE; LED_0805_2012Metric_Pad1.15x1.40mm_HandSolder
C28, C39: 0.1uF; C_0805_2012Metric_Pad1.18x1.45mm_HandSolder
C40: 10uF; C_0805_2012Metric_Pad1.18x1.45mm_HandSolder
H1, H2, H3, H4: MountingHole; MountingHole_3mm_Pad_TopOnly
J2: Conn_02x05_Odd_Even; PinHeader_2x05_P2.54mm_Vertical
MICROSD1: YELLOW; LED_0805_2012Metric_Pad1.15x1.40mm_HandSolder
R16, R17: 10k; R_0805_2012Metric_Pad1.20x1.40mm_HandSolder
R22, R23, R24, R28, R29, R30: 1k; R_0805_2012Metric_Pad1.20x1.40mm_HandSolder
R25: 330; R_0805_2012Metric_Pad1.20x1.40mm_HandSolder
R26, R27: 0; R_0805_2012Metric_Pad1.20x1.40mm_HandSolder
R31, R32: 100k; R_0805_2012Metric_Pad1.20x1.40mm_HandSolder
RS485RX1: GREEN; LED_0805_2012Metric_Pad1.15x1.40mm_HandSolder
RS485TX1: RED; LED_0805_2012Metric_Pad1.15x1.40mm_HandSolder
TEST1: WL-SFTW_3528_PLCC4; multicolorLED

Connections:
3.3VTARGET: R24.1; also elsewhere on the board
3.3VUSB: R23.1; also elsewhere on the board
+3.3V: C39.1, C40.1, J2.1, R16.1, R17.1, R28.1, R29.1, R30.1, R32.1, TEST1.1; also elsewhere on the board
+5V: R22.1; also elsewhere on the board
GND: 3V3TARGET1.1 (K), 3V3USB1.1 (K), 5V1.1 (K), C28.2, C39.2, C40.2, J2.3, J2.5, J2.9, R31.2; also elsewhere on the board
unnamed: 3V3TARGET1.2 (A), R24.2
unnamed: 3V3USB1.2 (A), R23.2
unnamed: 5V1.2 (A), R22.2
unnamed: MICROSD1.2 (A), R30.2
unnamed: R25.1, TEST1.3
unnamed: R26.1, TEST1.4
unnamed: R27.1, TEST1.2
unnamed: R29.2, RS485RX1.2 (A)
unnamed: R28.2, RS485TX1.2 (A)
PIO0_29: J2.6; also elsewhere on the board
PIO0_30: J2.7; also elsewhere on the board
PIO1_1: R25.2; also elsewhere on the board
PIO1_2: R27.2; also elsewhere on the board
PIO1_3: R26.2; also elsewhere on the board
ProISP: J2.8, R16.2; also elsewhere on the board
ProRESET: C28.1, J2.10, R17.2; also elsewhere on the board
ProSWDCLK: J2.4, R31.1; also elsewhere on the board
ProSWDIO: J2.2, R32.2; also elsewhere on the board
RS485RXLED: RS485RX1.1 (K); also elsewhere on the board
RS485TXLED: RS485TX1.1 (K); also elsewhere on the board
SDLED: MICROSD1.1 (K); also elsewhere on the board

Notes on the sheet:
These LEDs are manually toggled in firmware anytime comms are made to RS-485 TX / RX / MicroSD respectivelly
To reset the device, short ProRESET to ground.
In SWD mode, the UART pins can be used to print text to the console for debugging instead of using SWO which is not supported in this implementation. SWO needs to be routed to PIO0_10 which was a pain in the butt
Verify that these are the correct resistor values
By shorting this pin to ground during reset, the chip will mount as a USB drive allowing you to edit the firmware files. The LPC55S69 has a built in USB ROM Bootloader. This will not work under the current implementation because the USB1 port is connected. ISP requires the slower USB0 to be used. I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
PIO0_30/29 are FC0 UART TX/RX respectivally. You may wish to pull these high depending on application
J4 is for programming the ShamanLink MCU, GPIO testing, Reset Pin, and General Use
These 0 ohm resistor values are because the Green and Blue LEDs on this multicolor LED are 3.2 forward voltage. The headroom is very small and I am really just risking that the LED I buy happens to have forward voltages within the operating range. It may not work and it may fry the MCU GPIO pins pe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


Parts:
C25: 0.1uF; C_0805_2012Metric_Pad1.18x1.45mm_HandSolder
C26: 10uF; C_0805_2012Metric_Pad1.18x1.45mm_HandSolder
CR1, CR2, CR3: USBLC6-2SC6; SOT23-6L_STM-M
FB6: MFBW1V1608-601-R; R_0603_1608Metric_Pad0.98x0.95mm_HandSolder
J3: 0475710001; MOLEX_0475710001
R8, R9, R10, R11, R12: 10k; R_0805_2012Metric_Pad1.20x1.40mm_HandSolder
R21: 22; R_0805_2012Metric_Pad1.20x1.40mm_HandSolder
R34: 0; R_0805_2012Metric_Pad1.20x1.40mm_HandSolder

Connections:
+3.3V: C25.1, C26.1, CR1.5, CR2.5, CR3.5, J3.4 (VDD), R8.2, R9.2, R10.1, R11.1, R12.2; also elsewhere on the board
GND: C25.2, C26.2, CR1.2, CR2.2, CR3.2, FB6.1, J3.6 (VSS), R34.2; also elsewhere on the board
unnamed: CR3.3, R21.2
unnamed: CR3.4, J3.5 (CLK)
unnamed: CR3.6, J3.3 (CMD)
unnamed: CR1.6, J3.7 (DAT0)
unnamed: CR1.4, J3.8 (DAT1)
unnamed: CR2.6, J3.1 (DAT2)
unnamed: CR2.4, J3.2 (DAT3/CD)
unnamed: FB6.2, J3.9 (GND@1), J3.10 (GND@2), J3.13 (GND@3)
unnamed: J3.12 (POL), R34.1
PIO0_7: R21.1; also elsewhere on the board
PIO0_8: CR3.1, R8.1; also elsewhere on the board
PIO0_24: CR1.1, R11.2; also elsewhere on the board
PIO0_25: CR1.3, R10.2; also elsewhere on the board
PIO0_31: CR2.1, R12.1; also elsewhere on the board
PIO1_0: CR2.3, R9.1; also elsewhere on the board

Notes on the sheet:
This 0 ohm resistor is meant to be removable in the case that your MicroSD slot ends up being Normally closed. This would mean that POL needs to be tied high in order for the software to read "Card insterted" at all times. You will need a timeout in software in case no card is inserted to avoid loo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
Your layout implementation really isnt great. Consider forcing slow read/write speeds in software to avoid reflections and the large difference you have between line distances

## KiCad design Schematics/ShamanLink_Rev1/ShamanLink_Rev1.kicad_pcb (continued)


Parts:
C27, C38: 0.1uF; C_0805_2012Metric_Pad1.18x1.45mm_HandSolder
C37: 10uF; C_0805_2012Metric_Pad1.18x1.45mm_HandSolder
D2: SM712_SOT23; SOT-23_Handsoldering
J1: S6B-XH-A; JST_S6B-XH-A
R13: 120; R_1206_3216Metric_Pad1.30x1.75mm_HandSolder
R14, R15: 10k; R_0805_2012Metric_Pad1.20x1.40mm_HandSolder
U2: THVD1450D; D0008A_M

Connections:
+3.3V: C27.1, C37.1, C38.1, J1.1, R15.1, U2.8 (VCC); also elsewhere on the board
GND: C27.2, C37.2, C38.2, D2.3 (common), J1.4, R14.2, U2.5 (GND), U2.9 (PAD); also elsewhere on the board
unnamed: D2.1 (A1), J1.2, R13.1, U2.6 (A)
unnamed: D2.2 (A2), J1.3, R13.2, U2.7 (B)
PIO0_13: R15.2, U2.1 (R); also elsewhere on the board
PIO0_14: U2.4 (D); also elsewhere on the board
PIO0_20: R14.1, U2.2 (RE_N), U2.3 (DE); also elsewhere on the board

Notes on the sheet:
Dont Care, Could use this pin for a global emergency reset or to help the probe direct traffic


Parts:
C4, C18: 10uF; C_0805_2012Metric_Pad1.18x1.45mm_HandSolder
C16, C17: 100nF; C_0805_2012Metric_Pad1.18x1.45mm_HandSolder
C19, C21: 4.7uF; C_0805_2012Metric_Pad1.18x1.45mm_HandSolder
C20: 22uF; C_1206_3216Metric_Pad1.33x1.80mm_HandSolder
C22, C23, C24: 0.1uF; C_0805_2012Metric_Pad1.18x1.45mm_HandSolder
R5: 10kR; R_0805_2012Metric_Pad1.20x1.40mm_HandSolder
R6: 56kR; R_0805_2012Metric_Pad1.20x1.40mm_HandSolder
R7: 110kR; R_0805_2012Metric_Pad1.20x1.40mm_HandSolder
RST1: 100kR; R_0805_2012Metric_Pad1.20x1.40mm_HandSolder
SW1: SW_Push; SW_SPST_PTS645Sx43SMTR92
U3: AP7361C-33Y5-13; SOT89-5_DIO
U4: PTPS2117DRLR; SOT-5X3-8_DRL_TEX-M

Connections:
3.3VTARGET: C19.1, C24.1, R7.1, RST1.1, U4.3 (VIN1), U4.5 (MODE); also elsewhere on the board
3.3VUSB: C17.1, C18.1, C21.1, C22.1, U3.5 (OUT), U4.6 (VIN2); also elsewhere on the board
+3.3V: C20.1, C23.1, R5.1, U4.2 (VOUT), U4.7 (VOUT); also elsewhere on the board
+5V: C4.1, C16.1, U3.1 (EN), U3.4 (IN); also elsewhere on the board
GND: C4.2, C16.2, C17.2, C18.2, C19.2, C20.2, C21.2, C22.2, C23.2, C24.2, R6.2, SW1.2, U3.2 (GND), U4.1 (GND); also elsewhere on the board
unnamed: R6.1, R7.2, U4.4 (PR1)
unnamed: RST1.2, U4.8 (ST)
PRESET: R5.2, SW1.1; also elsewhere on the board

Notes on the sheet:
These two nets are global labels and not power labels atm. Be aware of design rules during layout


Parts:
C1, C2: 33pF; C_0805_2012Metric_Pad1.18x1.45mm_HandSolder
Y1: ECS-160-20-46X; XTAL_ECS-160-20-46X

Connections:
CLOCK32M_N: C2.1, Y1.1; also elsewhere on the board
CLOCK32M_P: C1.1, Y1.2; also elsewhere on the board
GND: C1.2, C2.2; also elsewhere on the board

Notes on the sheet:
Set the internal Capacitor banks on the MCU pins to 0pF, these external caps are sufficient



Board: 4 copper layers, 69.6 x 53.2 mm, 117 parts (22 on the bottom side), 76 nets.

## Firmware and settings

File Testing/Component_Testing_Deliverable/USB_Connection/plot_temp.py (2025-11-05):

import serial
import serial.tools.list_ports
import matplotlib.pyplot as plt
from matplotlib.animation import FuncAnimation
import time
import datetime
import csv
import binascii
import os
import atexit
import threading
import queue

# -------------------------------
# Configuration
# -------------------------------
# Replace with your Nucleo's virtual COM port or set to None to try auto-detect
COM_PORT = "COM7"
BAUD_RATE = 115200
MAX_POINTS = 100

# Quick mitigation / visualization options
# If True, values that look like Fahrenheit (>F_THRESHOLD) will be converted to Celsius
AUTO_CONVERT_F_TO_C = False
F_TO_C_THRESHOLD = 80.0  # If parsed value > this, assume Fahrenheit

# Exponential moving average for plotting (don't modify raw logged values)
USE_EMA = True
EMA_ALPHA = 0.2  # smoothing factor for EMA: higher = less smoothing

# Temporary override: if parsed temp looks obviously wrong (very large),
# divide it by DIVIDE_FACTOR before masking/EMA/plotting. This preserves
# `orig_temp` in the CSV while making the live plot reasonable.
ENABLE_DIVIDE_OVERRIDE = True
DIVIDE_THRESHOLD = 120.0
DIVIDE_FACTOR = 8.0

# Quick masking options: if the parsed temperature is clearly out-of-range
# (e.g. due to firmware/ADC issues), mask the plotted value by using the
# EMA/previous value or a clamp so the graph remains readable. Raw values
# and diagnostics are still logged to CSV and debug log.
ENABLE_MASKING = True
MIN_DISPLAY_TEMP = -40.0
MAX_DISPLAY_TEMP = 85.0

# Logging
LOG_FILE = "temperature_log.csv"

# Assumptions about incoming data:
# - Legacy single float per line: "23.5\n"
# - Structured CSV: "seq,temp,error_flag,device_timestamp,crc_hex"
#   Example: "123,24.7,0,1699070000.123,1a2b3c4d"
#   CRC is CRC32 (hex) of the payload before the crc field, encoded as utf-8.
# The parser will try the structured form first and gracefully fall back to legacy.


def find_mcu_port():
    ports = serial.tools.list_ports.comports()
    for port in ports:
        if 'STM32' in port.description or 'USB Serial' in port.description or 'Nucleo' in port.description:
            return port.device
    return None


# -------------------------------
# Initialize Serial
# -------------------------------
if COM_PORT is None:
    detected = find_mcu_port()
    if detected:
        COM_PORT = detected
    else:
        raise RuntimeError("No COM port specified and auto-detect failed")

ser = serial.Serial(COM_PORT, BAUD_RATE, timeout=1)


# -------------------------------
# Prepare real-time plot
# -------------------------------
try:
    plt.style.use('seaborn-darkgrid')
except OSError:
    # If seaborn is not installed or the style is not available, fall back
    # to the default matplotlib style and warn the user. Installing seaborn
    # (pip install seaborn) will provide the requested style.
    print("Warning: 'seaborn-darkgrid' style not found; falling back to default style."
          " To use seaborn styles install the 'seaborn' package.")
    plt.style.use('default')
fig, ax = plt.subplots()
ax.set_xlabel('Time (s)')
ax.set_ylabel('Temperature (°C)')
ax.set_title('STM32 Temperature Readings')

x_data, y_data = [], []
line, = ax.plot([], [], lw=2)
start_time = None
ema = None
last_good_display = None
line_queue = queue.Queue()


def serial_reader(ser, q):
    # Continuously read lines from serial and push (recv_time, bytes) to queue
    while True:
        try:
            b = ser.readline()
            if b:
                q.put((time.time(), b))
        except Exception:
            # On serial error, stop reader
            break


# start background reader thread so plotting and serial I/O are decoupled
reader_thread = threading.Thread(target=serial_reader, args=(ser, line_queue), daemon=True)
reader_thread.start()


# -------------------------------
# CSV Logger setup
# -------------------------------
log_file = open(LOG_FILE, 'a', newline='')
csv_writer = csv.writer(log_file)
if os.stat(LOG_FILE).st_size == 0:
    csv_writer.writerow([
        'host_iso_ts', 'seq', 'device_ts', 'relative_time_s', 'orig_temp', 'temp_c', 'display_temp', 'error_flag',
        'recv_crc', 'computed_crc', 'crc_ok', 'latency_s', 'masked', 'raw_line'
    ])
# Optional debug log file for firmware debug messages (lines starting with 'DBG:')
DEBUG_LOG_FILE = "serial_debug.log"
debug_log = open(DEBUG_LOG_FILE, 'a', newline='')


def safe_float(s):
    try:
        return float(s)
    except Exception:
        return None


def compute_crc32_hex(s: str) -> str:
    # return 8-char lowercase hex string
    return format(binascii.crc32(s.encode('utf-8')) & 0xFFFFFFFF, '08x')


def update(frame):
    global start_time
    global ema
    # Consume all available queued serial lines and process them
    processed = False
    while True:
        try:
            host_recv, line_bytes = line_queue.get_nowait()
        except queue.Empty:
            break

        processed = True
        host_iso = datetime.datetime.utcfromtimestamp(host_recv).isoformat()

        raw = line_bytes.decode('utf-8', errors='replace').strip()

        # If firmware printed a debug message (e.g., "DBG: raw=..."), handle it
        # separately so it doesn't get interpreted as a temperature sample.
        if 'DBG:' in raw:
            # write debug lines to a separate file and also print to console for visibility
            try:
                debug_log.write(f"{datetime.datetime.utcfromtimestamp(host_recv).isoformat()} {raw}\n")
                debug_log.flush()
            except Exception:
                pass
            # also print compact debug to console
            print(raw)
            # skip processing this line as a temperature sample
            continue
        seq = None
        temp = None
        orig_temp = None
        error_flag = None
        device_ts = None
        recv_crc = None
        computed_crc = None
        crc_ok = None
        latency = None

        fields = [f.strip() for f in raw.split(',') if f.strip() != '']
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

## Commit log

2026-02-24 Finished the ShamanLink PCB Design
    [MouserSearchDownload.csv, ShamanLink_Clock.kicad_sch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]
2026-02-24 Clarified SWO UART tradeoff implemenation
    [ShamanLink_Rev1.kicad_pcb, maintotemheader.kicad_sch, testing.kicad_sch]
2026-03-28 Add initial README for CAD files
2026-04-02 Final ShamanLink Revisions and Motor Totem Final Revisions
    [DCMotors.kicad_sch, LEDsGPIO.kicad_sch, MCU2.kicad_sch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]
2026-04-02 Added RS485 functionality to MainTotemLite
    [MCU2.kicad_sch, MainTotemHeader.kicad_sch, MainTotem_Rev1.kicad_sch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]
2026-04-07 Adding the MTL Schematics in post editing
    [100P_CONN.kicad_sch, 100Pin_Connector.kicad_sch, 40P_CONN.kicad_sch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]
2026-04-08 Layout Edits for Mezzanine Connector routing
    [100P_CONN.kicad_sch, 40P_CONN.kicad_sch, MCU2.kicad_sch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]
2026-04-08 Rerouting layout to resolve collision issues
    [100P_CONN.kicad_sch, MCU2.kicad_sch, MainTotemHeader.kicad_sch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]
2026-04-08 Adding Gerber and CAD files
    [MainTotem_Rev1-B_Mask.gbr, MainTotem_Rev1-B_Paste.gbr, MainTotem_Rev1-B_Silkscreen.gbr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]
2026-04-11 Computer Vision Module Alterations
    [ComputerVisionModule_Rev1.kicad_pcb, ComputerVisionModule_Rev1.kicad_sch, MainTotem_Rev1.kicad_pcb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]
2026-04-11 Added Bottom Module GPIO Demo board
    [ComputerVisionModule_Rev1.kicad_pcb, GPIOBottomModule.kicad_pcb, GPIOBottomModule.kicad_sch]
2026-04-26 CAD files and Schematic PDFs
    [ComputerVisionModule_Rev1-B_Mask.gbr, ComputerVisionModule_Rev1-B_Paste.gbr, ComputerVisionModule_Rev1-B_Silkscreen.gbr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]
